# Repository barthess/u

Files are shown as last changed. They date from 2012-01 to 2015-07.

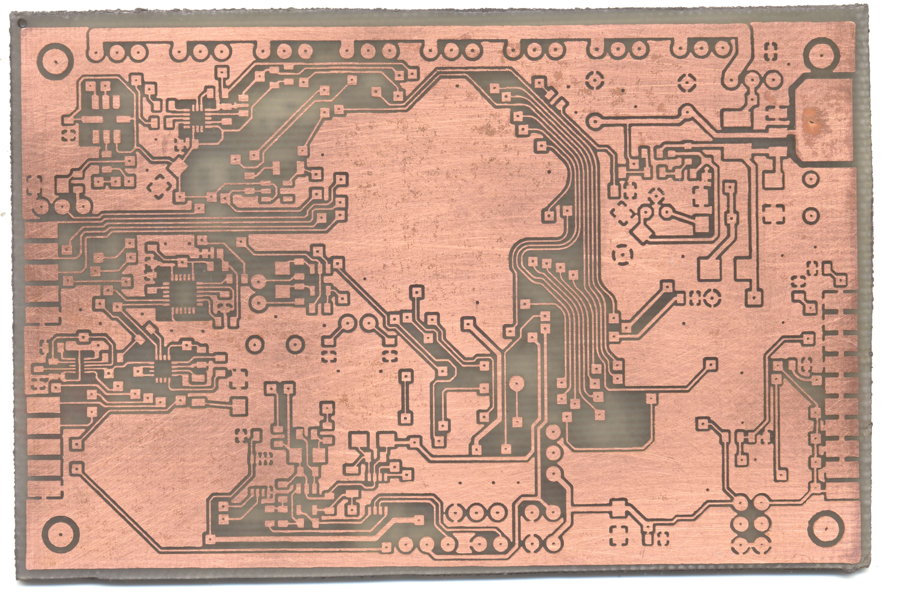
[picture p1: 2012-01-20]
hard/pcb/autopilot/pcb2.jpg

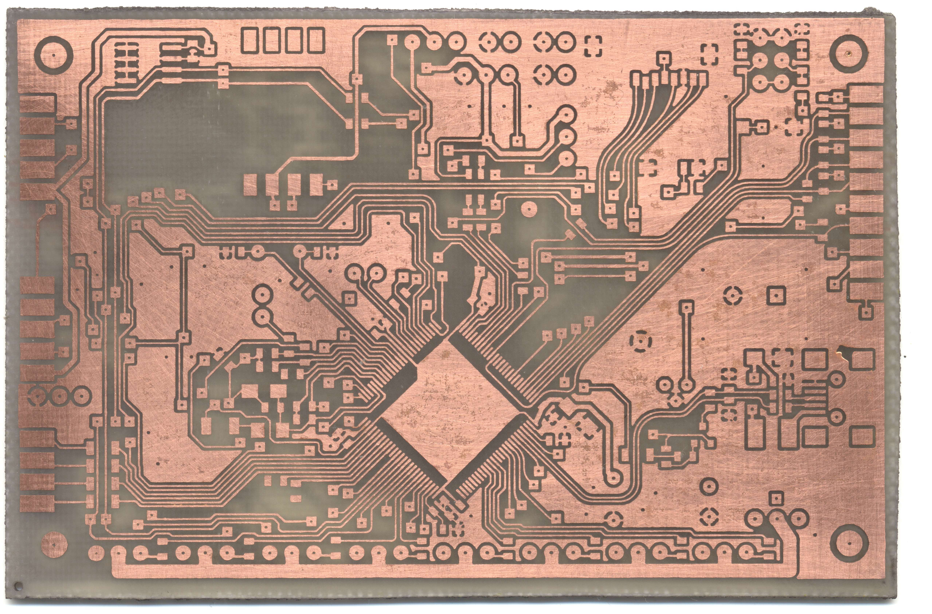
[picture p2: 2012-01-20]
hard/pcb/autopilot/pcb1.jpg

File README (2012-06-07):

A ChibiOS based autopilot. 

Goals of project:

0. Fun.
1. Education.

Copyright (C) 2012 Uladzimir Pylinski aka barthess (barthess@yandex.ru)

This program is free software: you can redistribute it and/or modify
it under the terms of the GNU General Public License as published by
the Free Software Foundation, either version 3 of the License, or
(at your option) any later version.

This program is distributed in the hope that it will be useful,
but WITHOUT ANY WARRANTY; without even the implied warranty of
MERCHANTABILITY or FITNESS FOR A PARTICULAR PURPOSE.  See the
GNU General Public License for more details.

You should have received a copy of the GNU General Public License
along with this program.  If not, see <http://www.gnu.org/licenses/>.

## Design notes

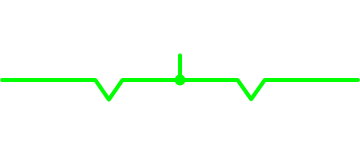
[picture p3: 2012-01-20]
soft/face/horizon_plane.png

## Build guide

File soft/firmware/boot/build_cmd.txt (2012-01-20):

 arm-none-eabi-gcc -mcpu=cortex-m3 -DTHUMB_PRESENT -mno-thumb-interwork -DTHUMB_NO_INTERWORKING -mthumb -DTHUMB -x assembler-with-cpp -c -g -O -Wa,-alh,-L boot.s -o ch.o

arm-none-eabi-ld -Tboot.ld -o ch.elf ch.o

arm-none-eabi-objcopy.exe -O binary ch.elf  ch.bin

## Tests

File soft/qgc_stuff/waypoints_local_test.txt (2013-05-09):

QGC WPL 120
0	1	1	22	0	1	0	0	14	0	520	1
1	0	1	21	0	1	0	0	4	2	520	1

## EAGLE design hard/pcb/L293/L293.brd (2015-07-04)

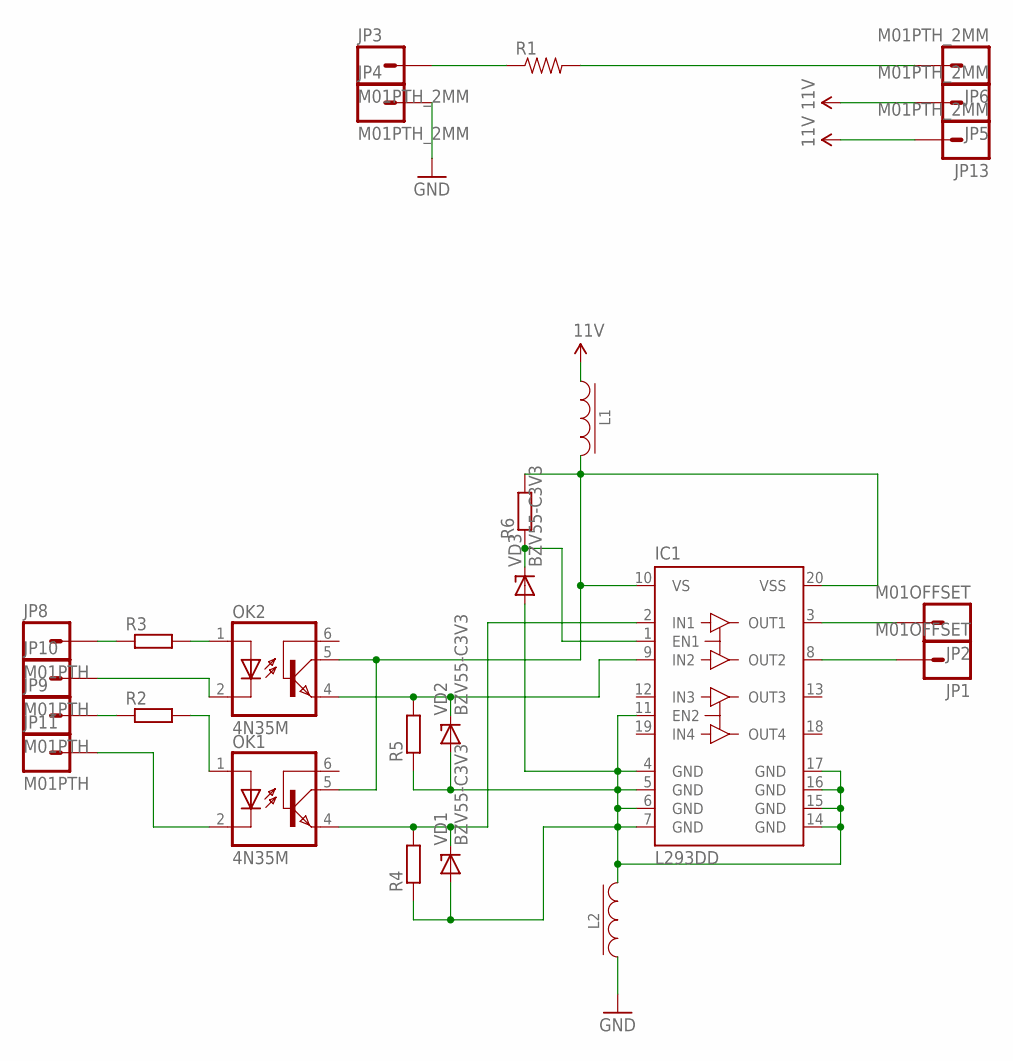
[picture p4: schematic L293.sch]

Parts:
IC1: L293DD; SO20
JP1, JP2: M01OFFSET; 1X01_OFFSET
JP3, JP4, JP5, JP6, JP13: M01PTH_2MM; 1X01_2MM
JP8, JP9, JP10, JP11: M01PTH; 1X01
L1, L2: DRA127
OK1, OK2: 4N35M; DIL06
R1: RESISTOR2512; R2512
R2, R3, R4, R5, R6: RESISTOR0805; 0805
VD1, VD2, VD3: BZV55-C3V3; SOD80C

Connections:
1.0V: JP5.1, JP13.1, L1.1
GND: JP4.1, L2.1
GND_DIRT: IC1.4 (GND), IC1.5 (GND), IC1.6 (GND), IC1.7 (GND), IC1.11 (EN2), IC1.14 (GND), IC1.15 (GND), IC1.16 (GND), IC1.17 (GND), L2.2, R4.1, R5.1, VD1.A, VD2.A, VD3.A
unnamed: IC1.8 (OUT2), JP1.1
unnamed: IC1.3 (OUT1), JP2.1
unnamed: JP3.1, R1.1
unnamed: JP6.1, R1.2
unnamed: JP9.1, R2.1
unnamed: JP8.1, R3.1
unnamed: IC1.10 (VS), IC1.20 (VSS), L1.2, OK1.5 (COL), OK2.5 (COL), R6.2
unnamed: OK1.1 (A), R2.2
unnamed: JP11.1, OK1.2 (C)
unnamed: JP10.1, OK2.2 (C)
unnamed: OK2.1 (A), R3.2
unnamed: IC1.1 (EN1), R6.1, VD3.C
unnamed: IC1.9 (IN2), OK2.4 (EMI), R5.2, VD2.C
unnamed: IC1.2 (IN1), OK1.4 (EMI), R4.2, VD1.C

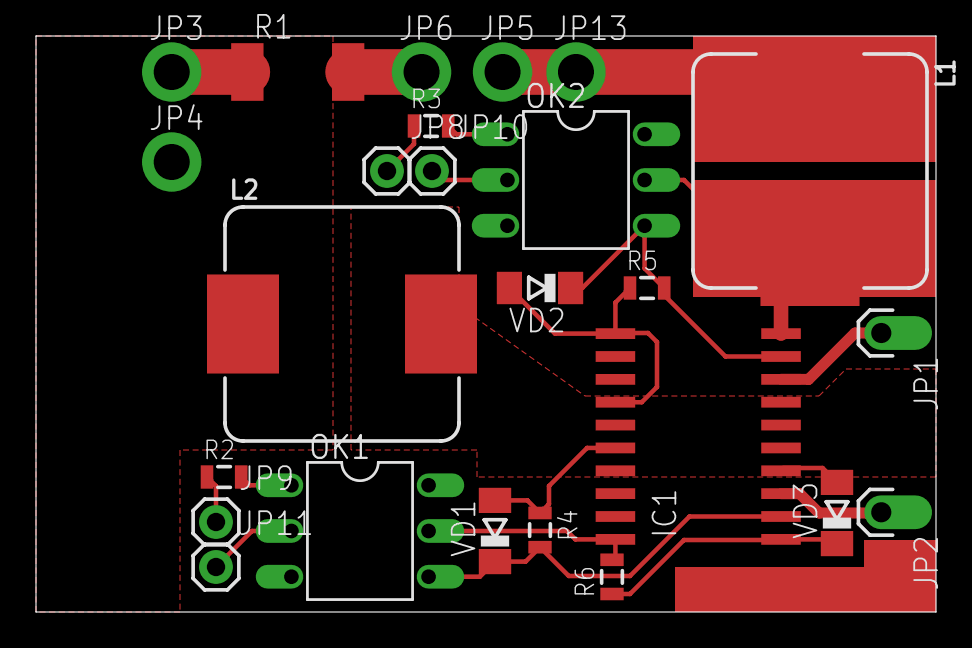
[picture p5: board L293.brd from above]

Board: 2 copper layers, 50.0 x 32.0 mm, 25 parts (0 on the bottom side), 17 nets.

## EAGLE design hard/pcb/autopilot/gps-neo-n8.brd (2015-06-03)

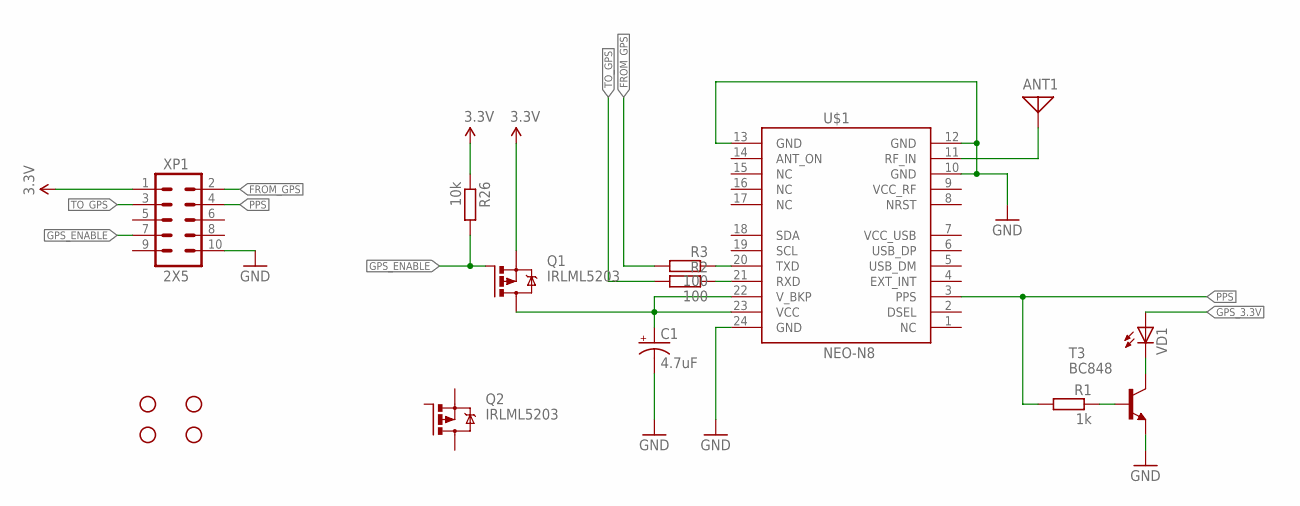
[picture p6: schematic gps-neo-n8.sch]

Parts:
ANT1: GPS_ANTENNA'35X35'; GPS_ANT_35X35MM
C1: 4.7uF; EIA3216-KIT
JP1, JP2, JP4, JP5: STAND-OFF
Q1, Q2: IRLML5203; MICRO3
R1: 1k; R0805
R2, R3: 100; R0805
R26: 10k; R0805
T3: BC848; SOT23
U$1: NEO-N8; NEO-M8
VD1: LED0805; LED-0805
XP1: 2X5; 2X5-PSEUDOSMD

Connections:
3.3V: Q1.2 (S), R26.1, XP1.1
FROM_GPS: R3.2, XP1.2
GND: C1.C (-), T3.2 (E), U$1.10 (GND), U$1.12 (GND), U$1.13 (GND), U$1.24 (GND), XP1.10
GPS_3.3V: C1.A (+), Q1.3 (D), U$1.22 (V_BKP), U$1.23 (VCC), VD1.A
GPS_ENABLE: Q1.1 (G), R26.2, XP1.7
unnamed: T3.3 (C), VD1.C
unnamed: ANT1.1, U$1.11 (RF_IN)
unnamed: R1.1, T3.1 (B)
unnamed: R2.1, U$1.21 (RXD)
unnamed: R3.1, U$1.20 (TXD)
PPS: R1.2, U$1.3 (PPS), XP1.4
TO_GPS: R2.2, XP1.3
VCC_RF: U$1.9 (VCC_RF)

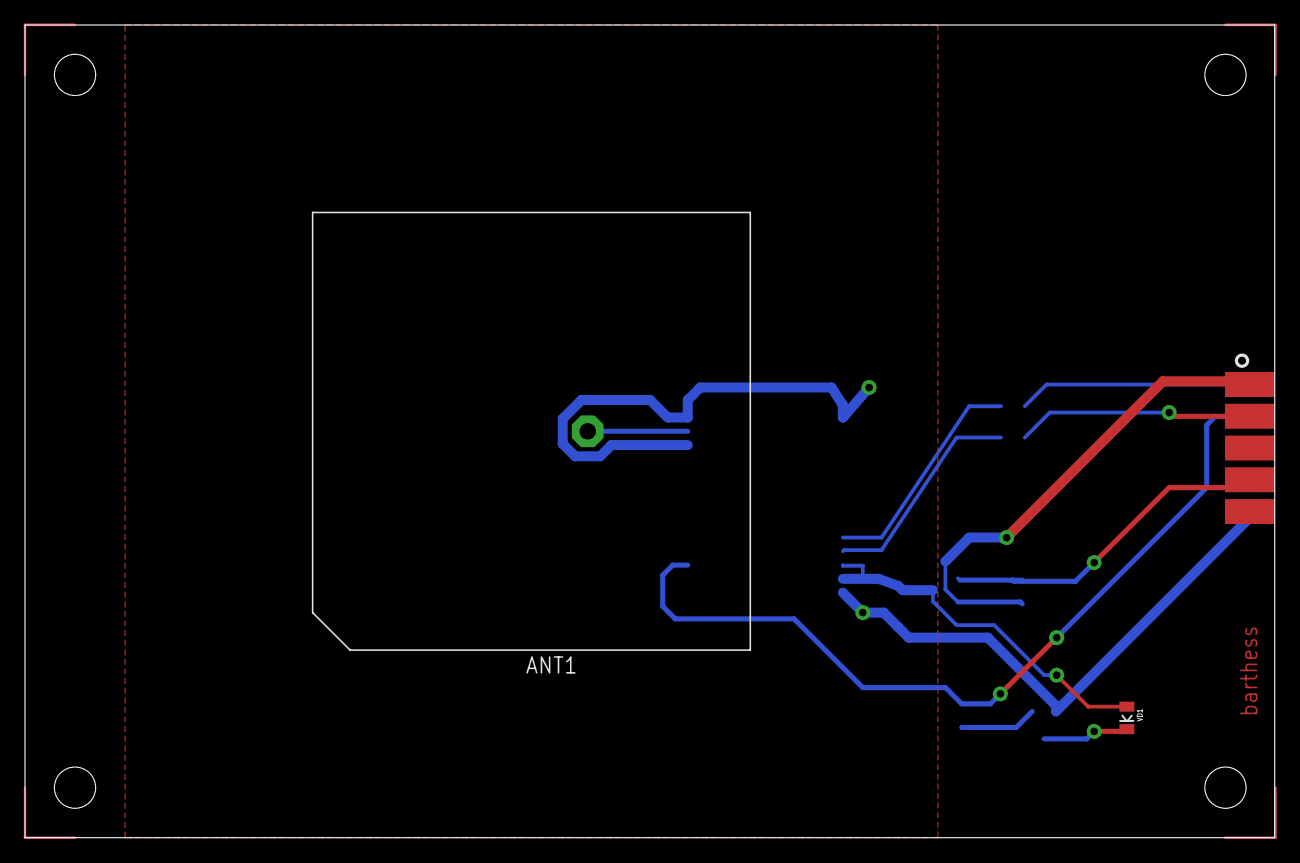
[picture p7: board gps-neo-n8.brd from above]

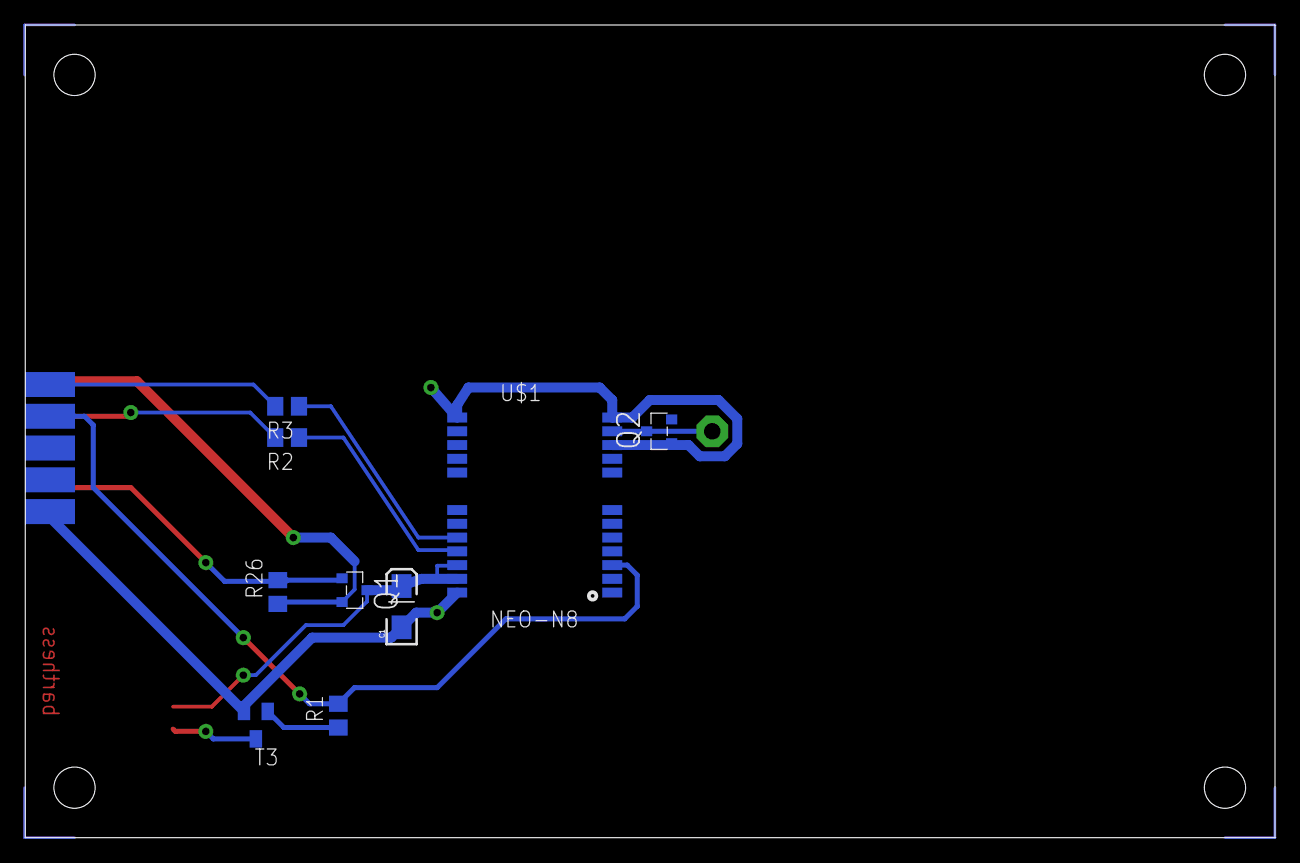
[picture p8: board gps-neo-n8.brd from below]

Board: 2 copper layers, 99.9 x 65.0 mm, 17 parts (9 on the bottom side), 12 nets.

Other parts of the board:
U$2: LOGO_CHIBIOS_SIGNAL

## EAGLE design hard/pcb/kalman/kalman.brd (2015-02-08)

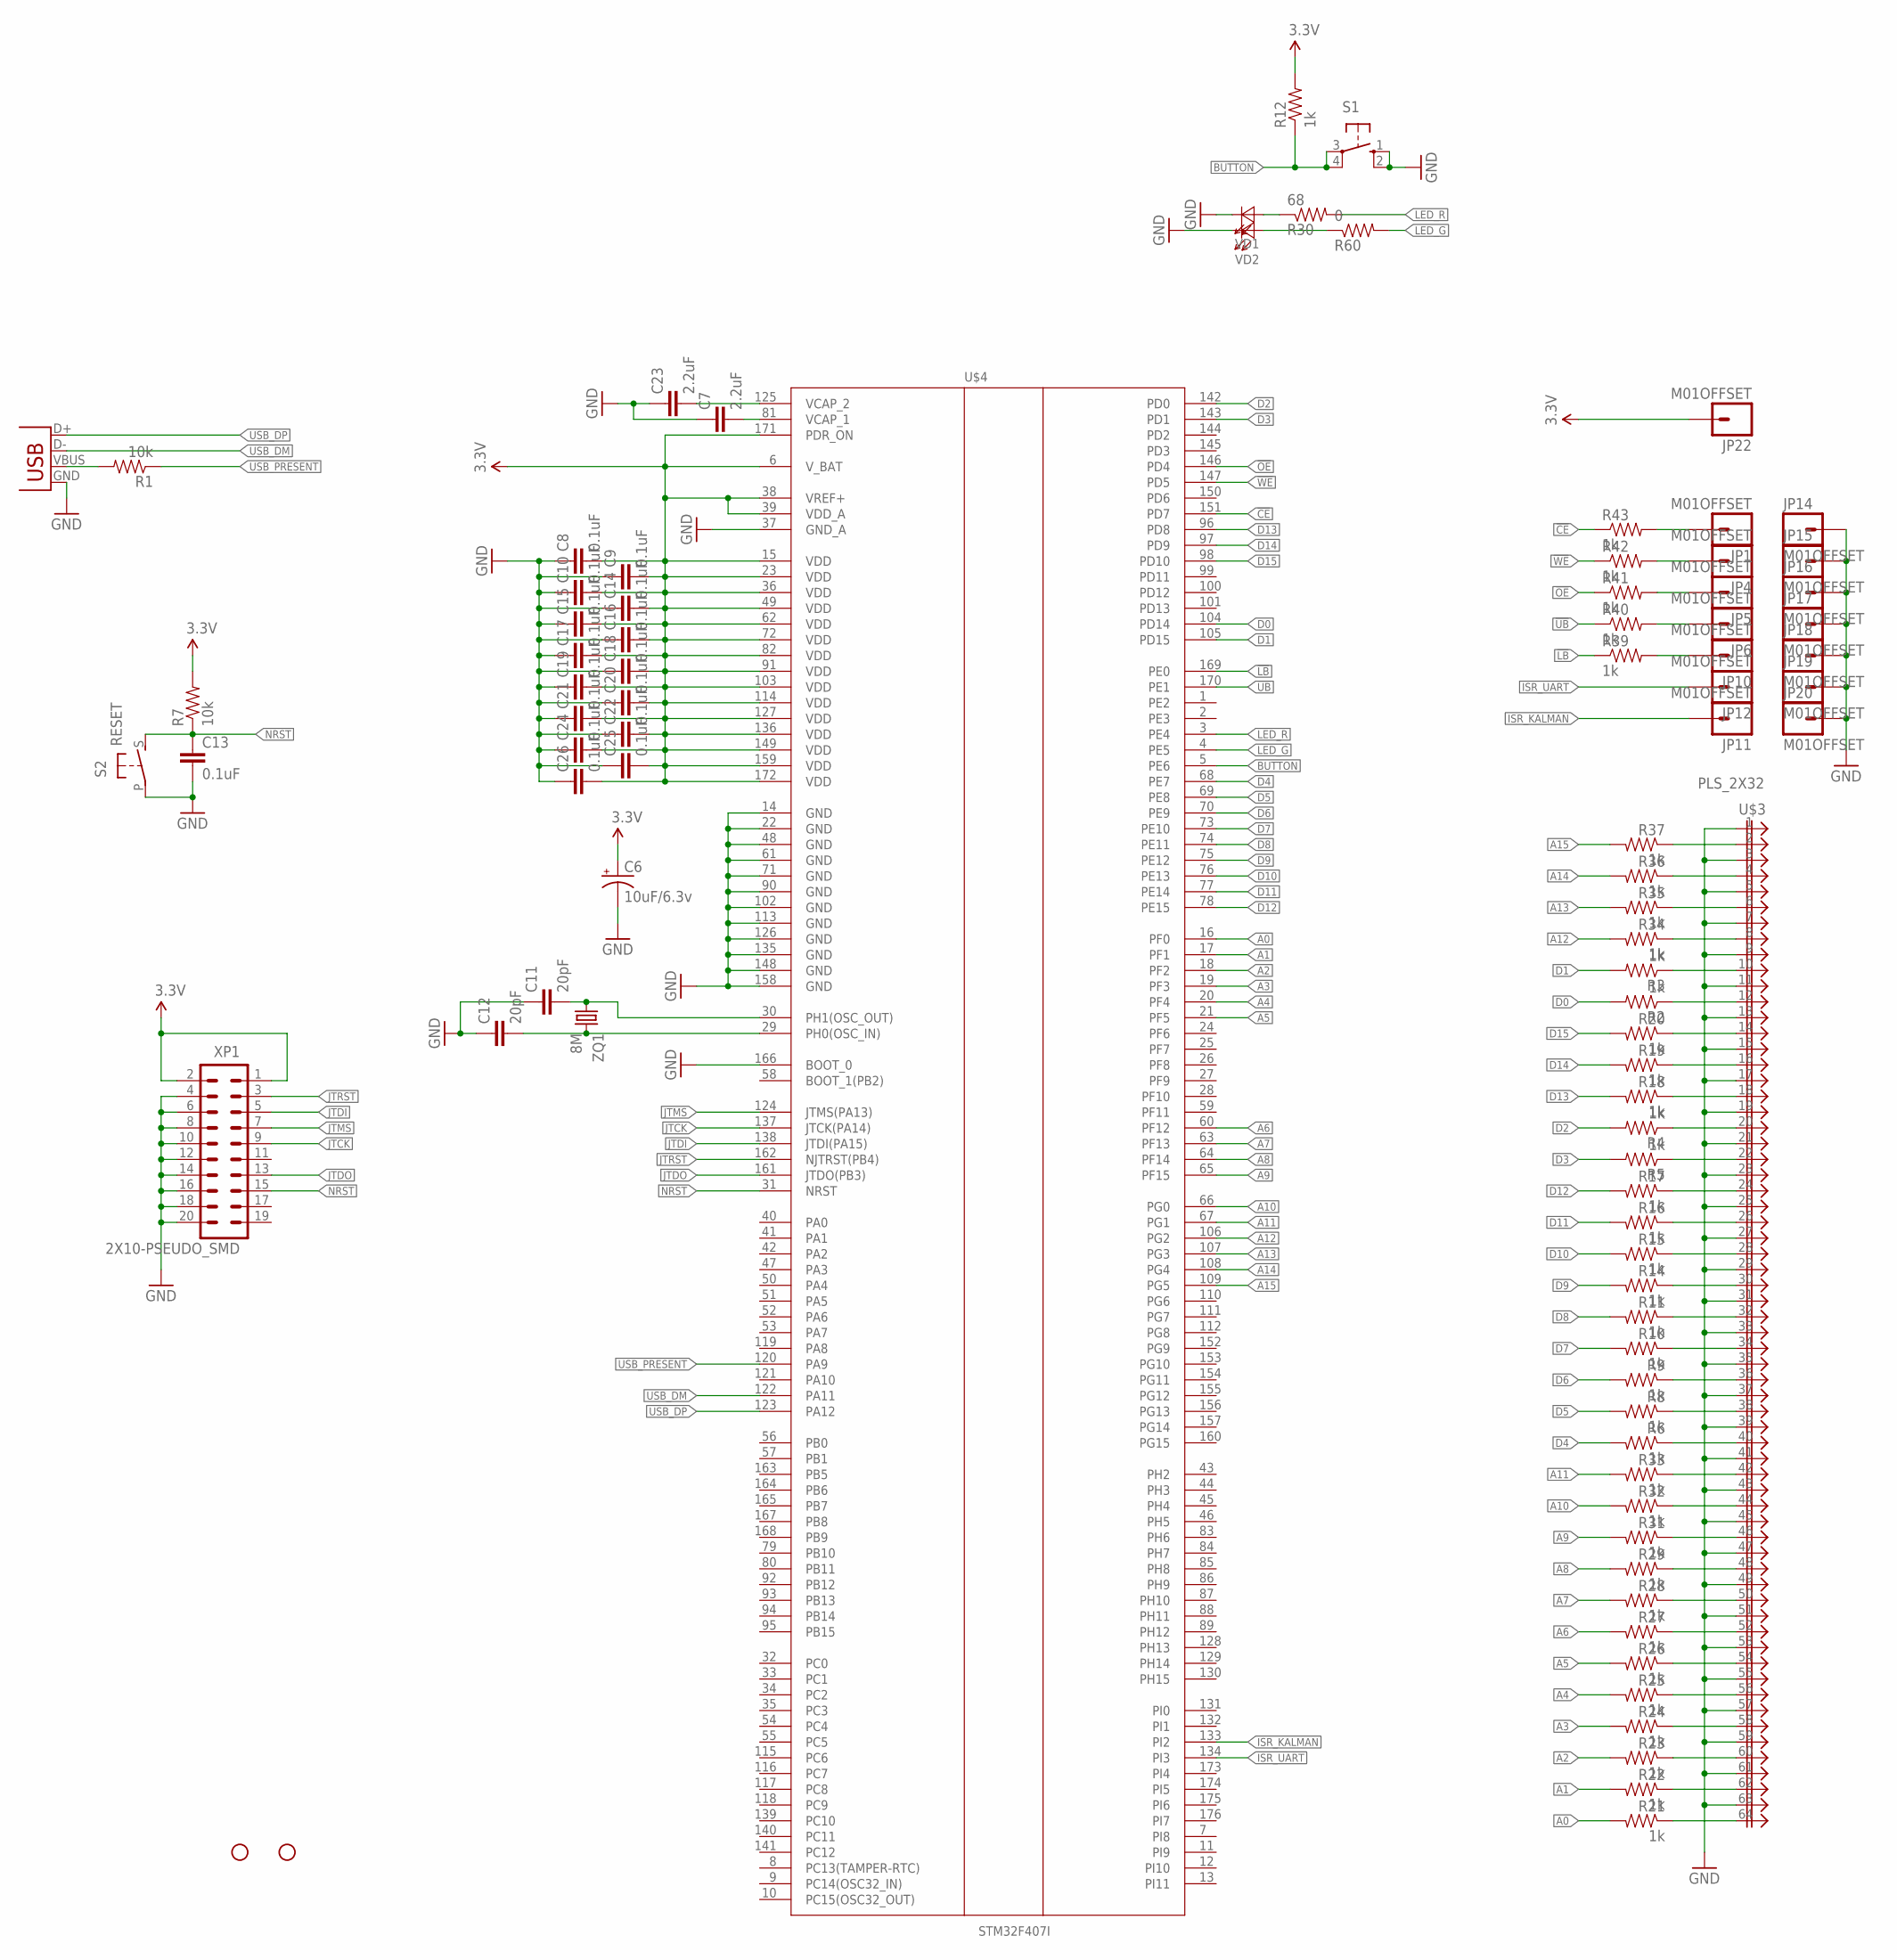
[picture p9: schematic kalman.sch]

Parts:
C6: 10uF/6.3v; EIA3216-KIT
C7, C23: 2.2uF; 0805
C8, C9, C10, C13, C14, C15, C16, C17, C18, C19, C20, C21, C22, C24, C25, C26: 0.1uF; 0805
C11, C12: 20pF; 0805
JP1, JP4, JP5, JP6, JP10, JP11, JP12, JP14, JP15, JP16, JP17, JP18, JP19, JP20, JP22: M01OFFSET; 1X01_OFFSET
JP7, JP8: STAND-OFF
R1, R7: 10k; 0805
R2, R3, R4, R5, R6, R8, R9, R10, R11, R12, R14, R15, R16, R17, R18, R19, R20, R21, R22, R23, R24, R25, R26, R27, R28, R29, R31, R32, R33, R34, R35, R36, R37, R39, R40, R41, R42, R43: 1k; 0805
R30: 68; 0805
R60: 0; 0805
S1: 10-XX; B3F-10XX
S2: RESET; BUTTON_6X3.5
U$3: PLS_2X32; PLS_2X32_PSEUDOSMD
U$4: STM32F407I; TQFP176(1.5X0.25)
VD1, VD2: LED1206; LED-1206
X1: USB-SMD-NS; USB-MINIB-NOSTOP
XP1: 2X10-PSEUDO_SMD; PLD_2X10_PSEUDOSMD
ZQ1: 8M; CTS406

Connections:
3.3V: C6.A (+), C8.2, C9.2, C10.2, C14.2, C15.2, C16.2, C17.2, C18.2, C19.2, C20.2, C21.2, C22.2, C24.2, C25.2, C26.2, JP22.1, R7.2, R12.2, U$4.6 (V_BAT), U$4.15 (VDD), U$4.23 (VDD), U$4.36 (VDD), U$4.38 (VREF+), U$4.39 (VDD_A), U$4.49 (VDD), U$4.62 (VDD), U$4.72 (VDD), U$4.82 (VDD), U$4.91 (VDD), U$4.103 (VDD), U$4.114 (VDD), U$4.127 (VDD), U$4.136 (VDD), U$4.149 (VDD), U$4.159 (VDD), U$4.171 (PDR_ON), U$4.172 (VDD), XP1.1, XP1.2
5V_USB: R1.2, X1.VBUS
!CE: R43.1, U$4.151 (PD7)
!LB: R39.1, U$4.169 (PE0)
!OE: R41.1, U$4.146 (PD4)
!UB: R40.1, U$4.170 (PE1)
!WE: R42.1, U$4.147 (PD5)
A0: R21.2, U$4.16 (PF0)
A1: R22.2, U$4.17 (PF1)
A2: R23.2, U$4.18 (PF2)
A3: R24.2, U$4.19 (PF3)
A4: R25.2, U$4.20 (PF4)
A5: R26.2, U$4.21 (PF5)
A6: R27.2, U$4.60 (PF12)
A7: R28.2, U$4.63 (PF13)
A8: R29.2, U$4.64 (PF14)
A9: R31.2, U$4.65 (PF15)
A10: R32.2, U$4.66 (PG0)
A11: R33.2, U$4.67 (PG1)
A12: R34.2, U$4.106 (PG2)
A13: R35.2, U$4.107 (PG3)
A14: R36.2, U$4.108 (PG4)
A15: R37.2, U$4.109 (PG5)
BUTTON: R12.1, S1.3, S1.4 (P1), U$4.5 (PE6)
D0: R2.2, U$4.104 (PD14)
D1: R3.2, U$4.105 (PD15)
D2: R4.2, U$4.142 (PD0)
D3: R5.2, U$4.143 (PD1)
D4: R6.2, U$4.68 (PE7)
D5: R8.2, U$4.69 (PE8)
D6: R9.2, U$4.70 (PE9)
D7: R10.2, U$4.73 (PE10)
D8: R11.2, U$4.74 (PE11)
D9: R14.2, U$4.75 (PE12)
D10: R15.2, U$4.76 (PE13)
D11: R16.2, U$4.77 (PE14)
D12: R17.2, U$4.78 (PE15)
D13: R18.2, U$4.96 (PD8)
D14: R19.2, U$4.97 (PD9)
D15: R20.2, U$4.98 (PD10)
GND: C6.C (-), C7.1, C8.1, C9.1, C10.1, C11.1, C12.1, C13.2, C14.1, C15.1, C16.1, C17.1, C18.1, C19.1, C20.1, C21.1, C22.1, C23.1, C24.1, C25.1, C26.1, JP14.1, JP15.1, JP16.1, JP17.1, JP18.1, JP19.1, JP20.1, S1.1 (S), S1.2 (S1), S2.P, U$3.1, U$3.3, U$3.5, U$3.7, U$3.9, U$3.11, U$3.13, U$3.15, U$3.17, U$3.19, U$3.21, U$3.23, U$3.25, U$3.27, U$3.29, U$3.31, U$3.33, U$3.35, U$3.37, U$3.39, U$3.41, U$3.43, U$3.45, U$3.47, U$3.49, U$3.51, U$3.53, U$3.55, U$3.57, U$3.59, U$3.61, U$3.63, U$4.14 (GND), U$4.22 (GND), U$4.37 (GND_A), U$4.48 (GND), U$4.61 (GND), U$4.71 (GND), U$4.90 (GND), U$4.102 (GND), U$4.113 (GND), U$4.126 (GND), U$4.135 (GND), U$4.148 (GND), U$4.158 (GND), U$4.166 (BOOT_0), VD1.C, VD2.C, X1.GND, XP1.4, XP1.6, XP1.8, XP1.10, XP1.12, XP1.14, XP1.16, XP1.18, XP1.20
ISR_KALMAN: JP11.1, U$4.133 (PI2)
ISR_UART: JP12.1, U$4.134 (PI3)
JTCK: U$4.137 (JTCK(PA14)), XP1.9
JTDI: U$4.138 (JTDI(PA15)), XP1.5
JTDO: U$4.161 (JTDO(PB3)), XP1.13
JTMS: U$4.124 (JTMS(PA13)), XP1.7
JTRST: U$4.162 (NJTRST(PB4)), XP1.3
LED_G: R60.2, U$4.4 (PE5)
LED_R: R30.2, U$4.3 (PE4)
unnamed: C23.2, U$4.125 (VCAP_2)
unnamed: C7.2, U$4.81 (VCAP_1)
unnamed: JP1.1, R43.2
unnamed: R5.1, U$3.22
unnamed: R4.1, U$3.20
unnamed: R18.1, U$3.18
unnamed: R19.1, U$3.16
unnamed: R6.1, U$3.40
unnamed: R8.1, U$3.38
unnamed: R21.1, U$3.64
unnamed: R9.1, U$3.36
unnamed: R30.1, VD1.A
unnamed: R22.1, U$3.62
unnamed: R10.1, U$3.34
unnamed: R11.1, U$3.32
unnamed: R14.1, U$3.30
unnamed: R15.1, U$3.28
unnamed: R16.1, U$3.26
unnamed: R17.1, U$3.24
unnamed: R20.1, U$3.14
unnamed: C12.2, U$4.29 (PH0(OSC_IN)), ZQ1.3 (2)
unnamed: C11.2, U$4.30 (PH1(OSC_OUT)), ZQ1.1
unnamed: R2.1, U$3.12
unnamed: R3.1, U$3.10
unnamed: R23.1, U$3.60
unnamed: R24.1, U$3.58
unnamed: R25.1, U$3.56
unnamed: R26.1, U$3.54
unnamed: R27.1, U$3.52
unnamed: R28.1, U$3.50
unnamed: R60.1, VD2.A
unnamed: R29.1, U$3.48
unnamed: R31.1, U$3.46
unnamed: R32.1, U$3.44
unnamed: R33.1, U$3.42
unnamed: R34.1, U$3.8
unnamed: R35.1, U$3.6
unnamed: R36.1, U$3.4
unnamed: R37.1, U$3.2
unnamed: JP4.1, R42.2
unnamed: JP5.1, R41.2
unnamed: JP6.1, R40.2
unnamed: JP10.1, R39.2
NRST: C13.1, R7.1, S2.S, U$4.31 (NRST), XP1.15
USB_DM: U$4.122 (PA11), X1.D-
USB_DP: U$4.123 (PA12), X1.D+
USB_PRESENT: R1.1, U$4.120 (PA9)

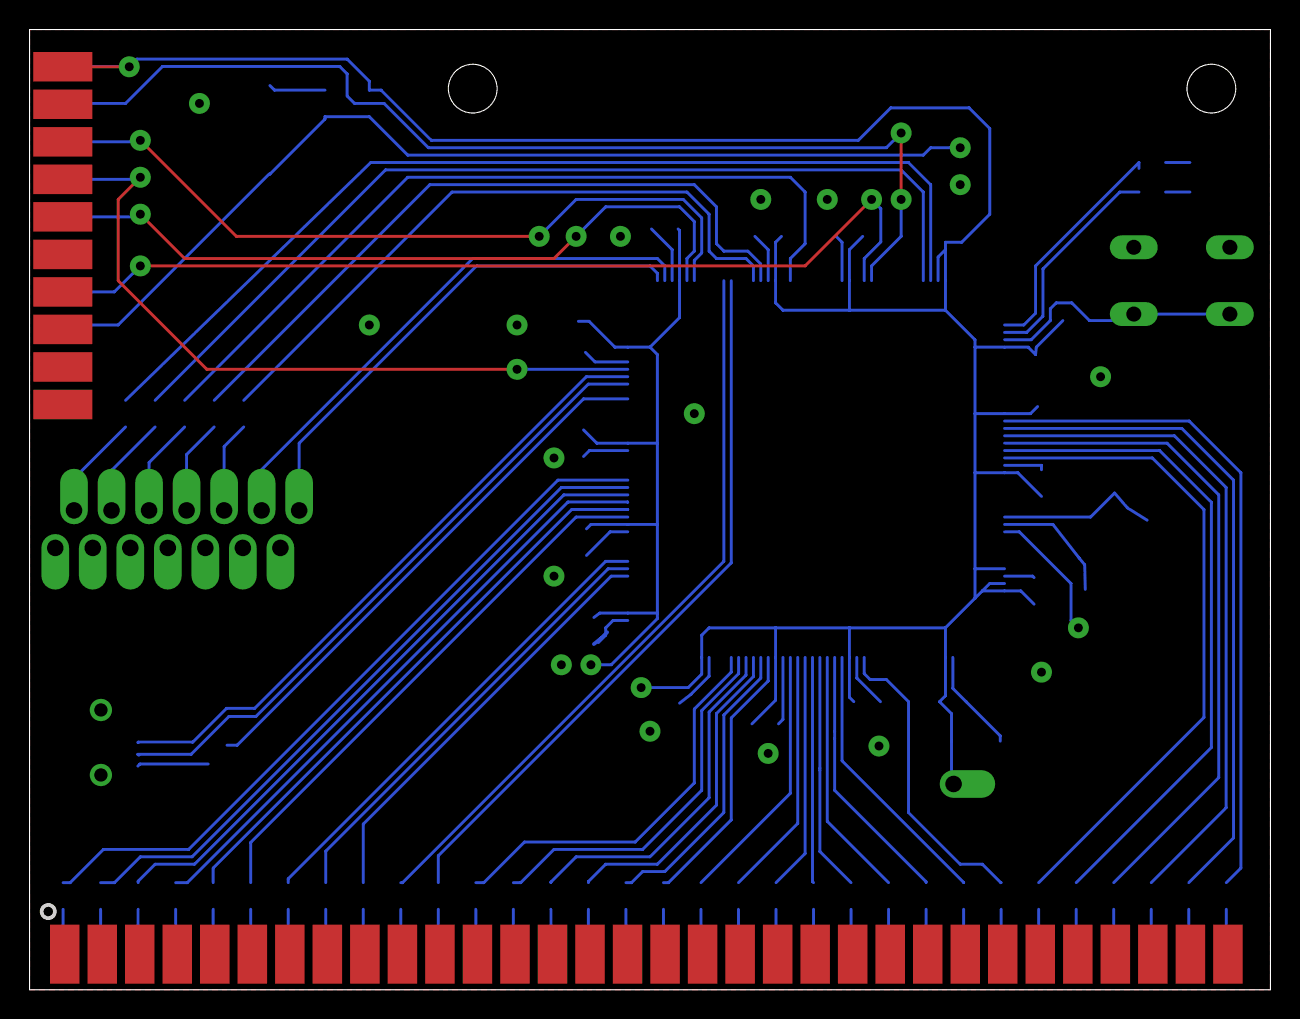
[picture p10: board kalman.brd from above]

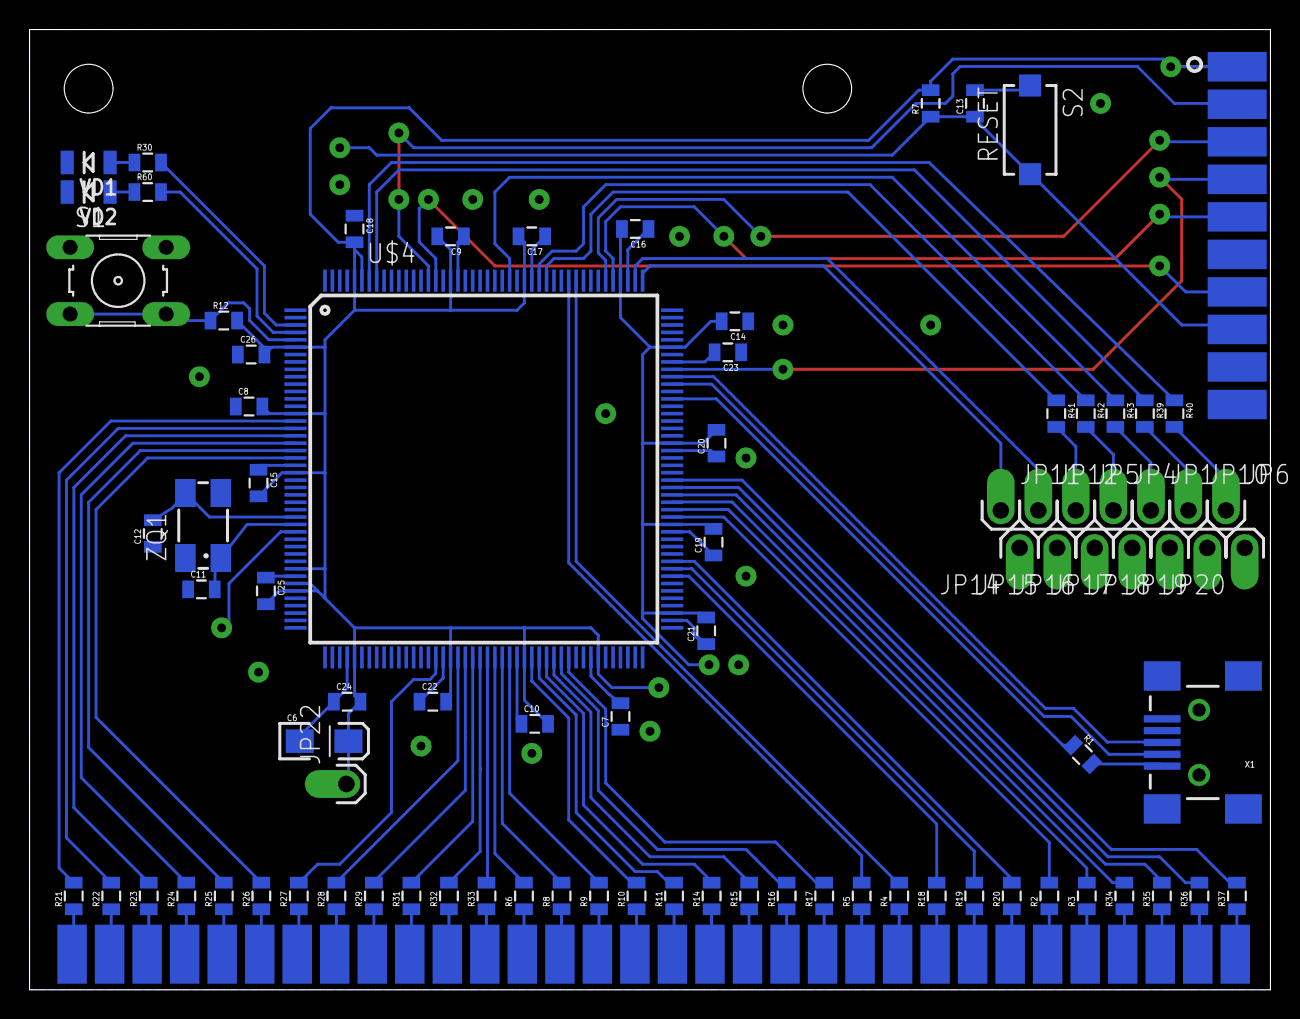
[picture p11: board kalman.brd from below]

Board: 2 copper layers, 84.0 x 65.0 mm, 89 parts (86 on the bottom side), 97 nets.

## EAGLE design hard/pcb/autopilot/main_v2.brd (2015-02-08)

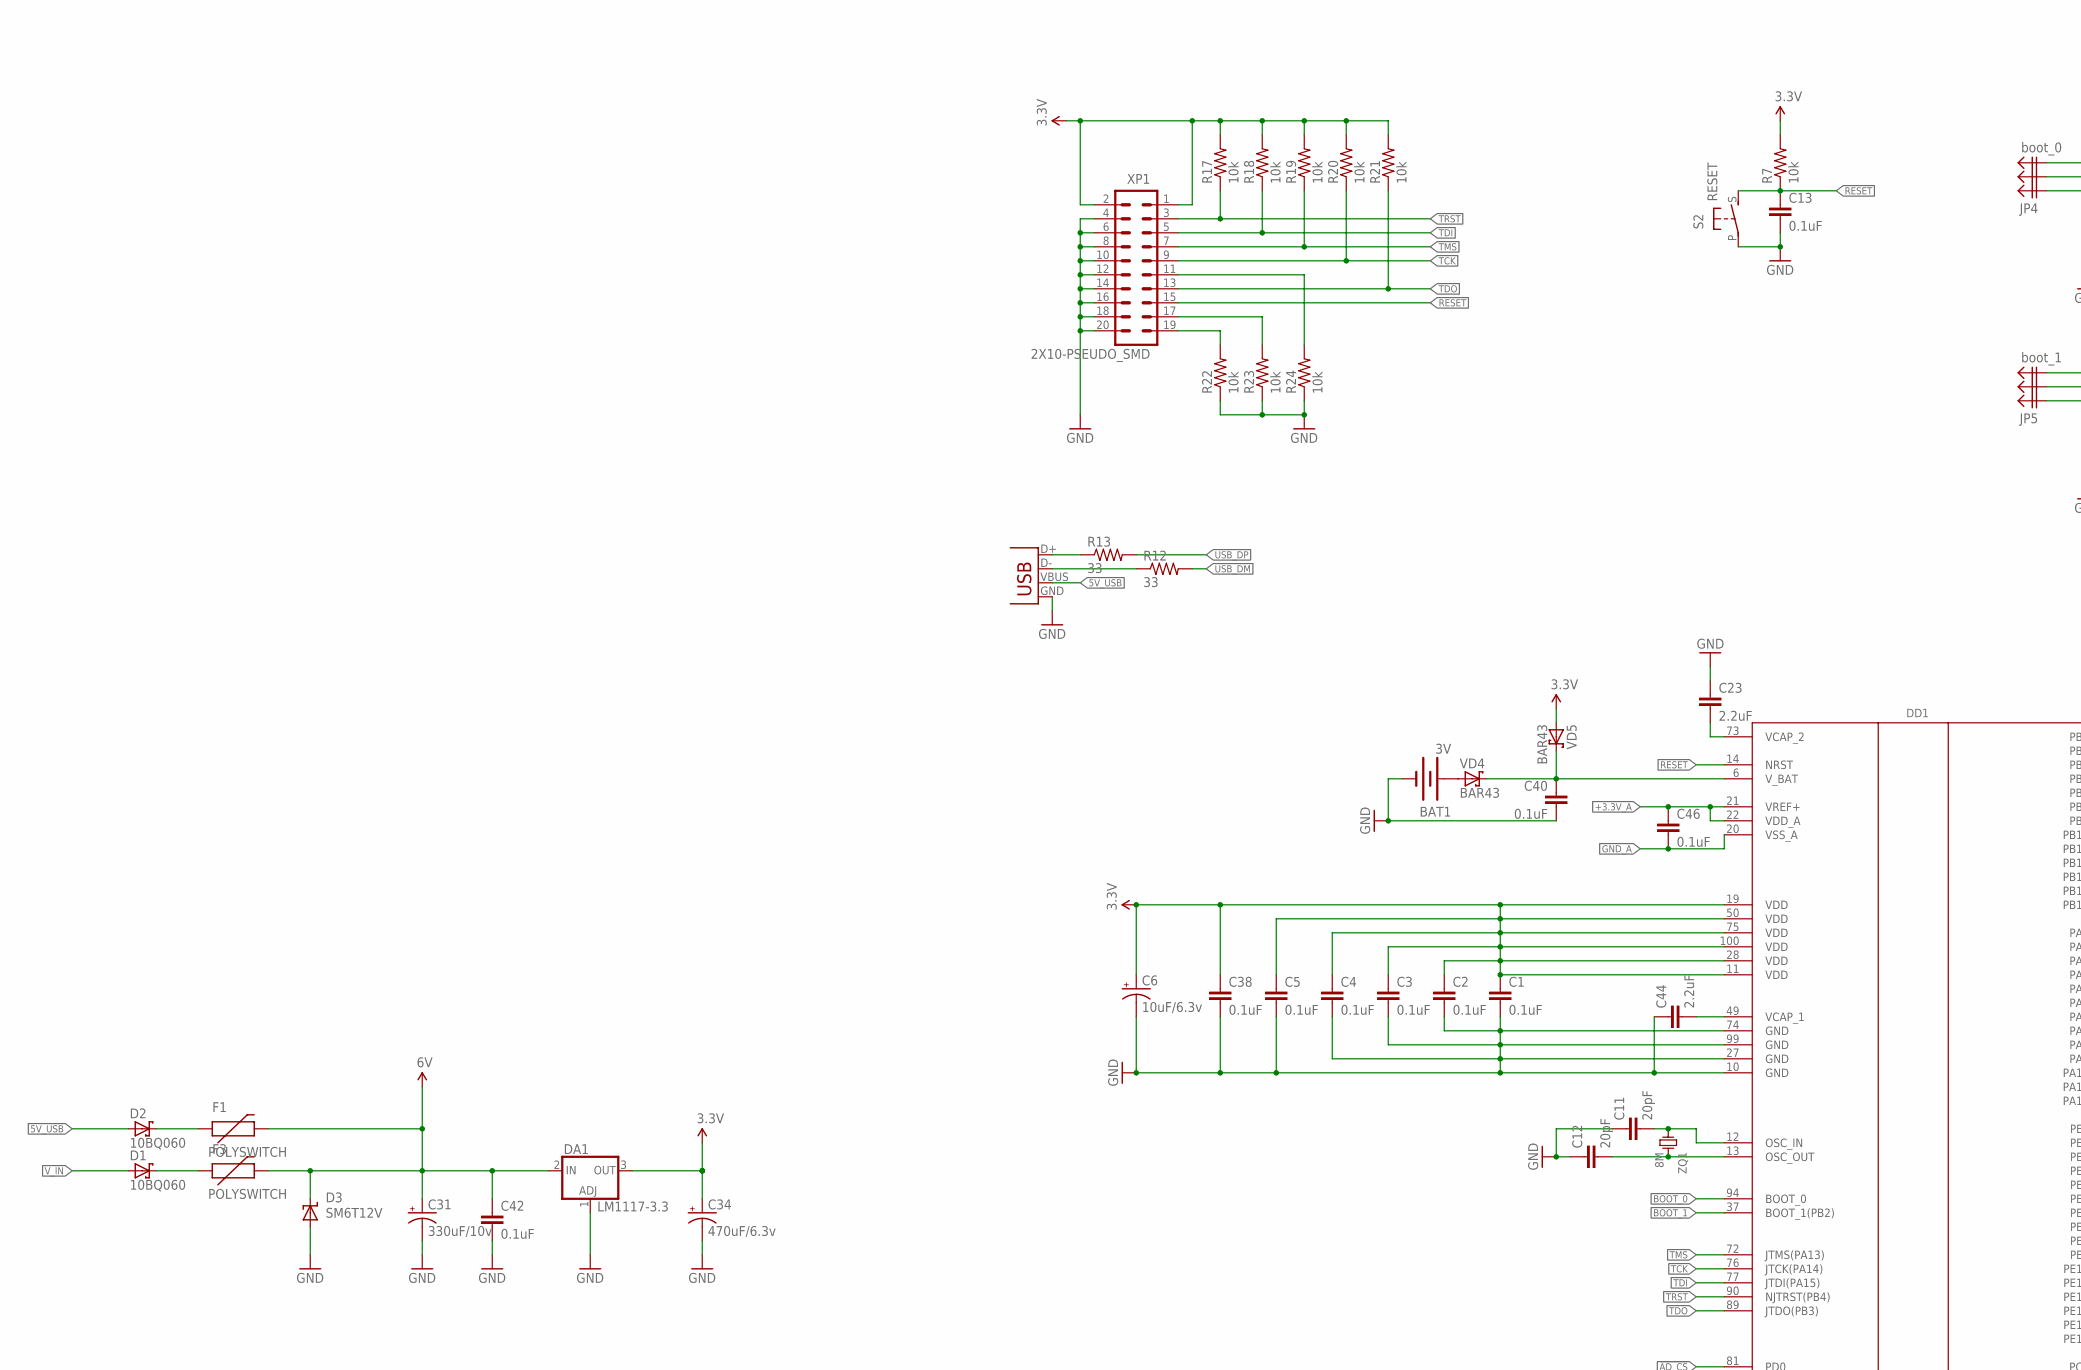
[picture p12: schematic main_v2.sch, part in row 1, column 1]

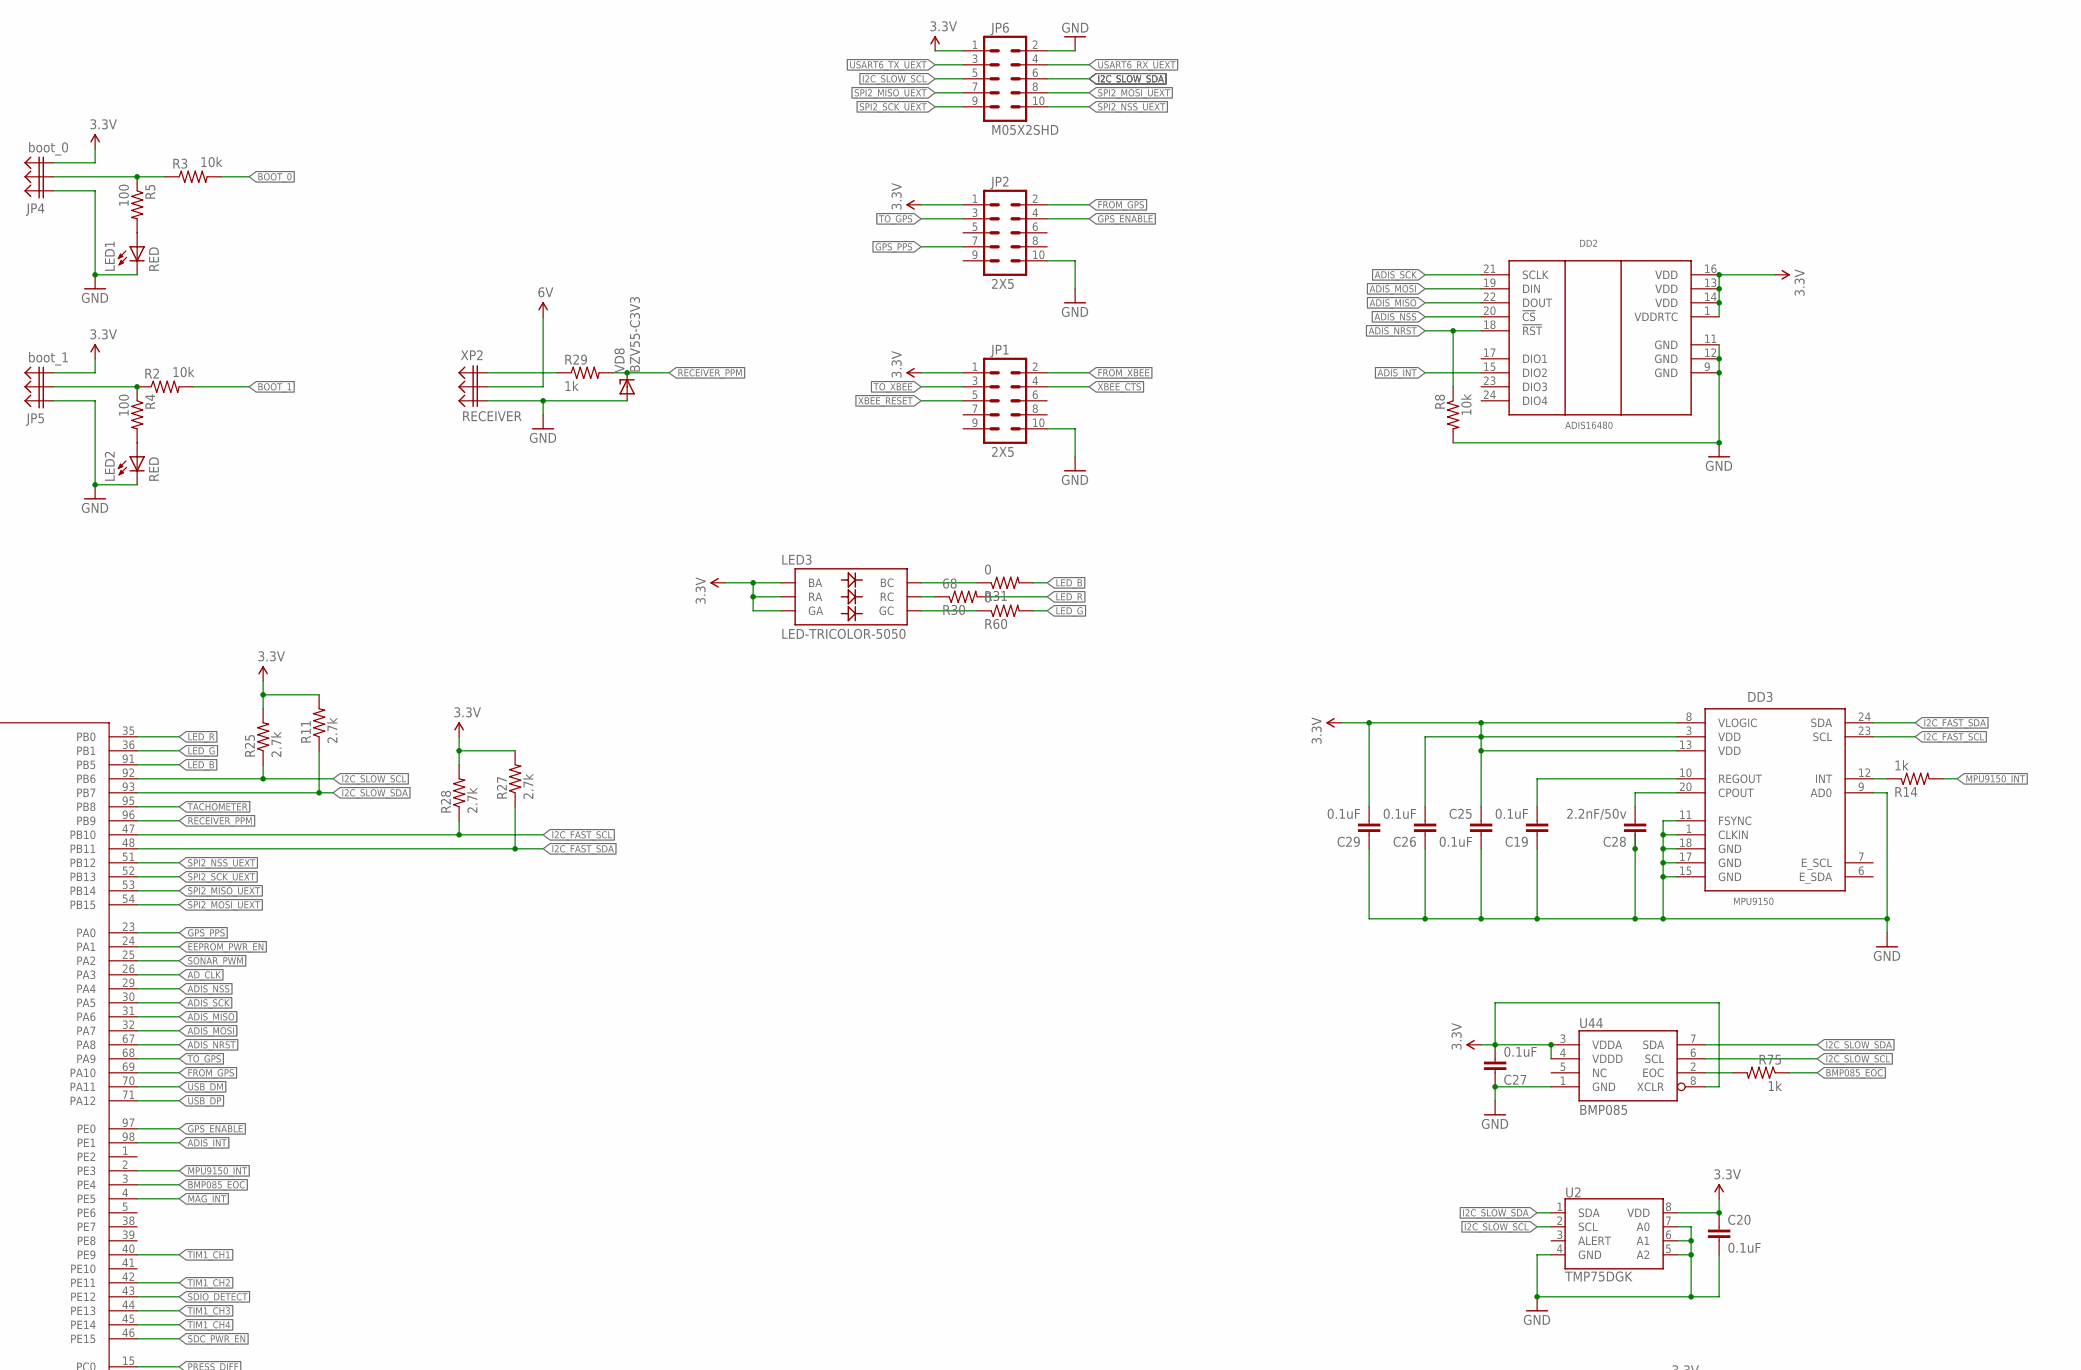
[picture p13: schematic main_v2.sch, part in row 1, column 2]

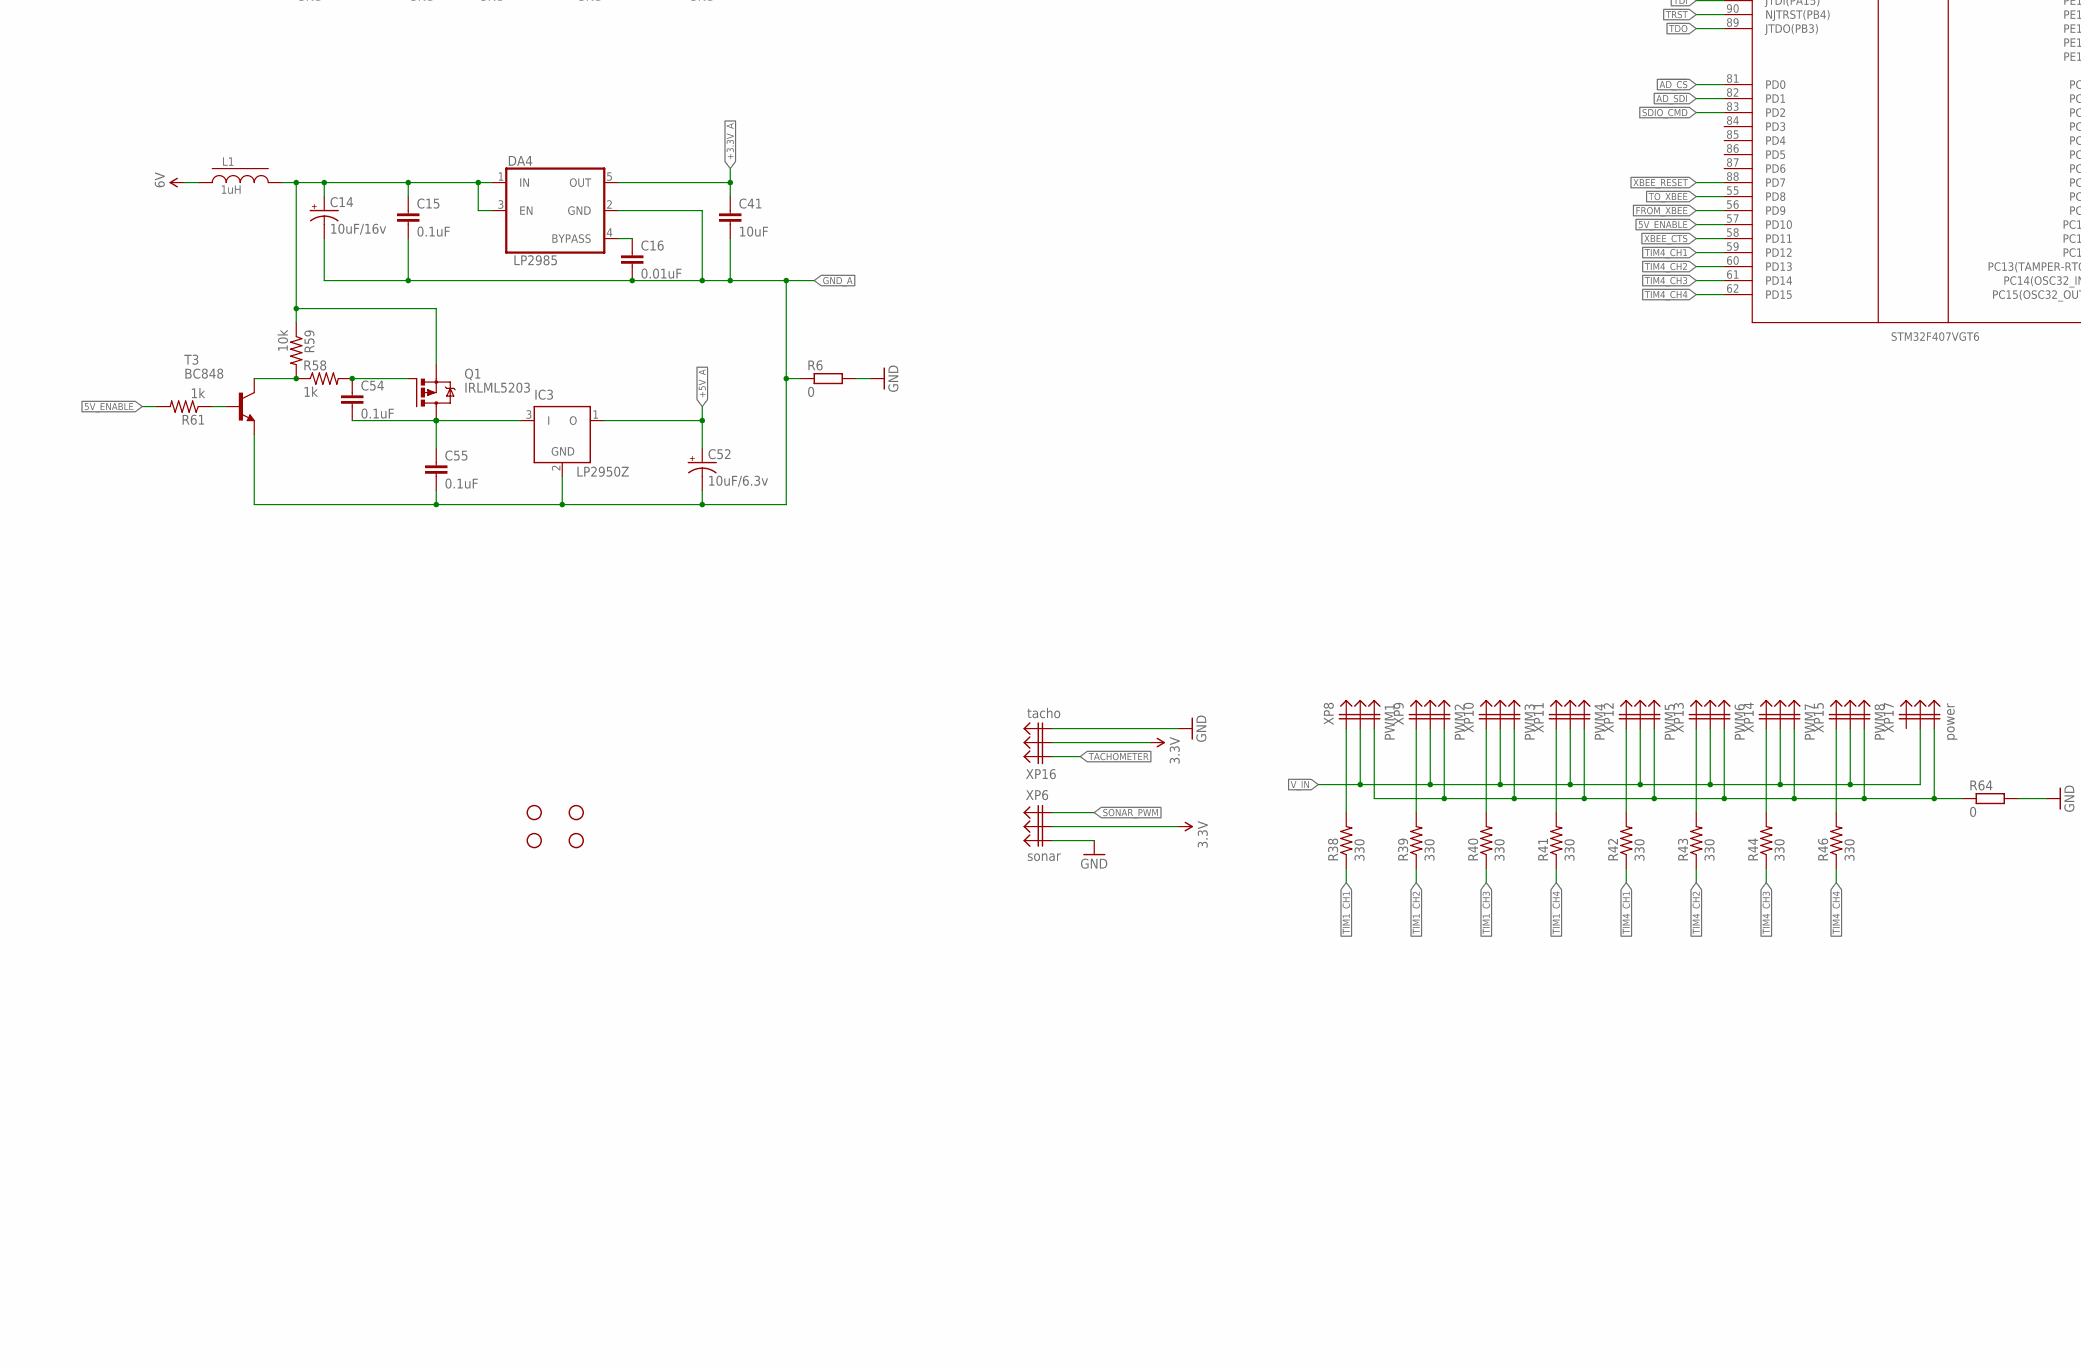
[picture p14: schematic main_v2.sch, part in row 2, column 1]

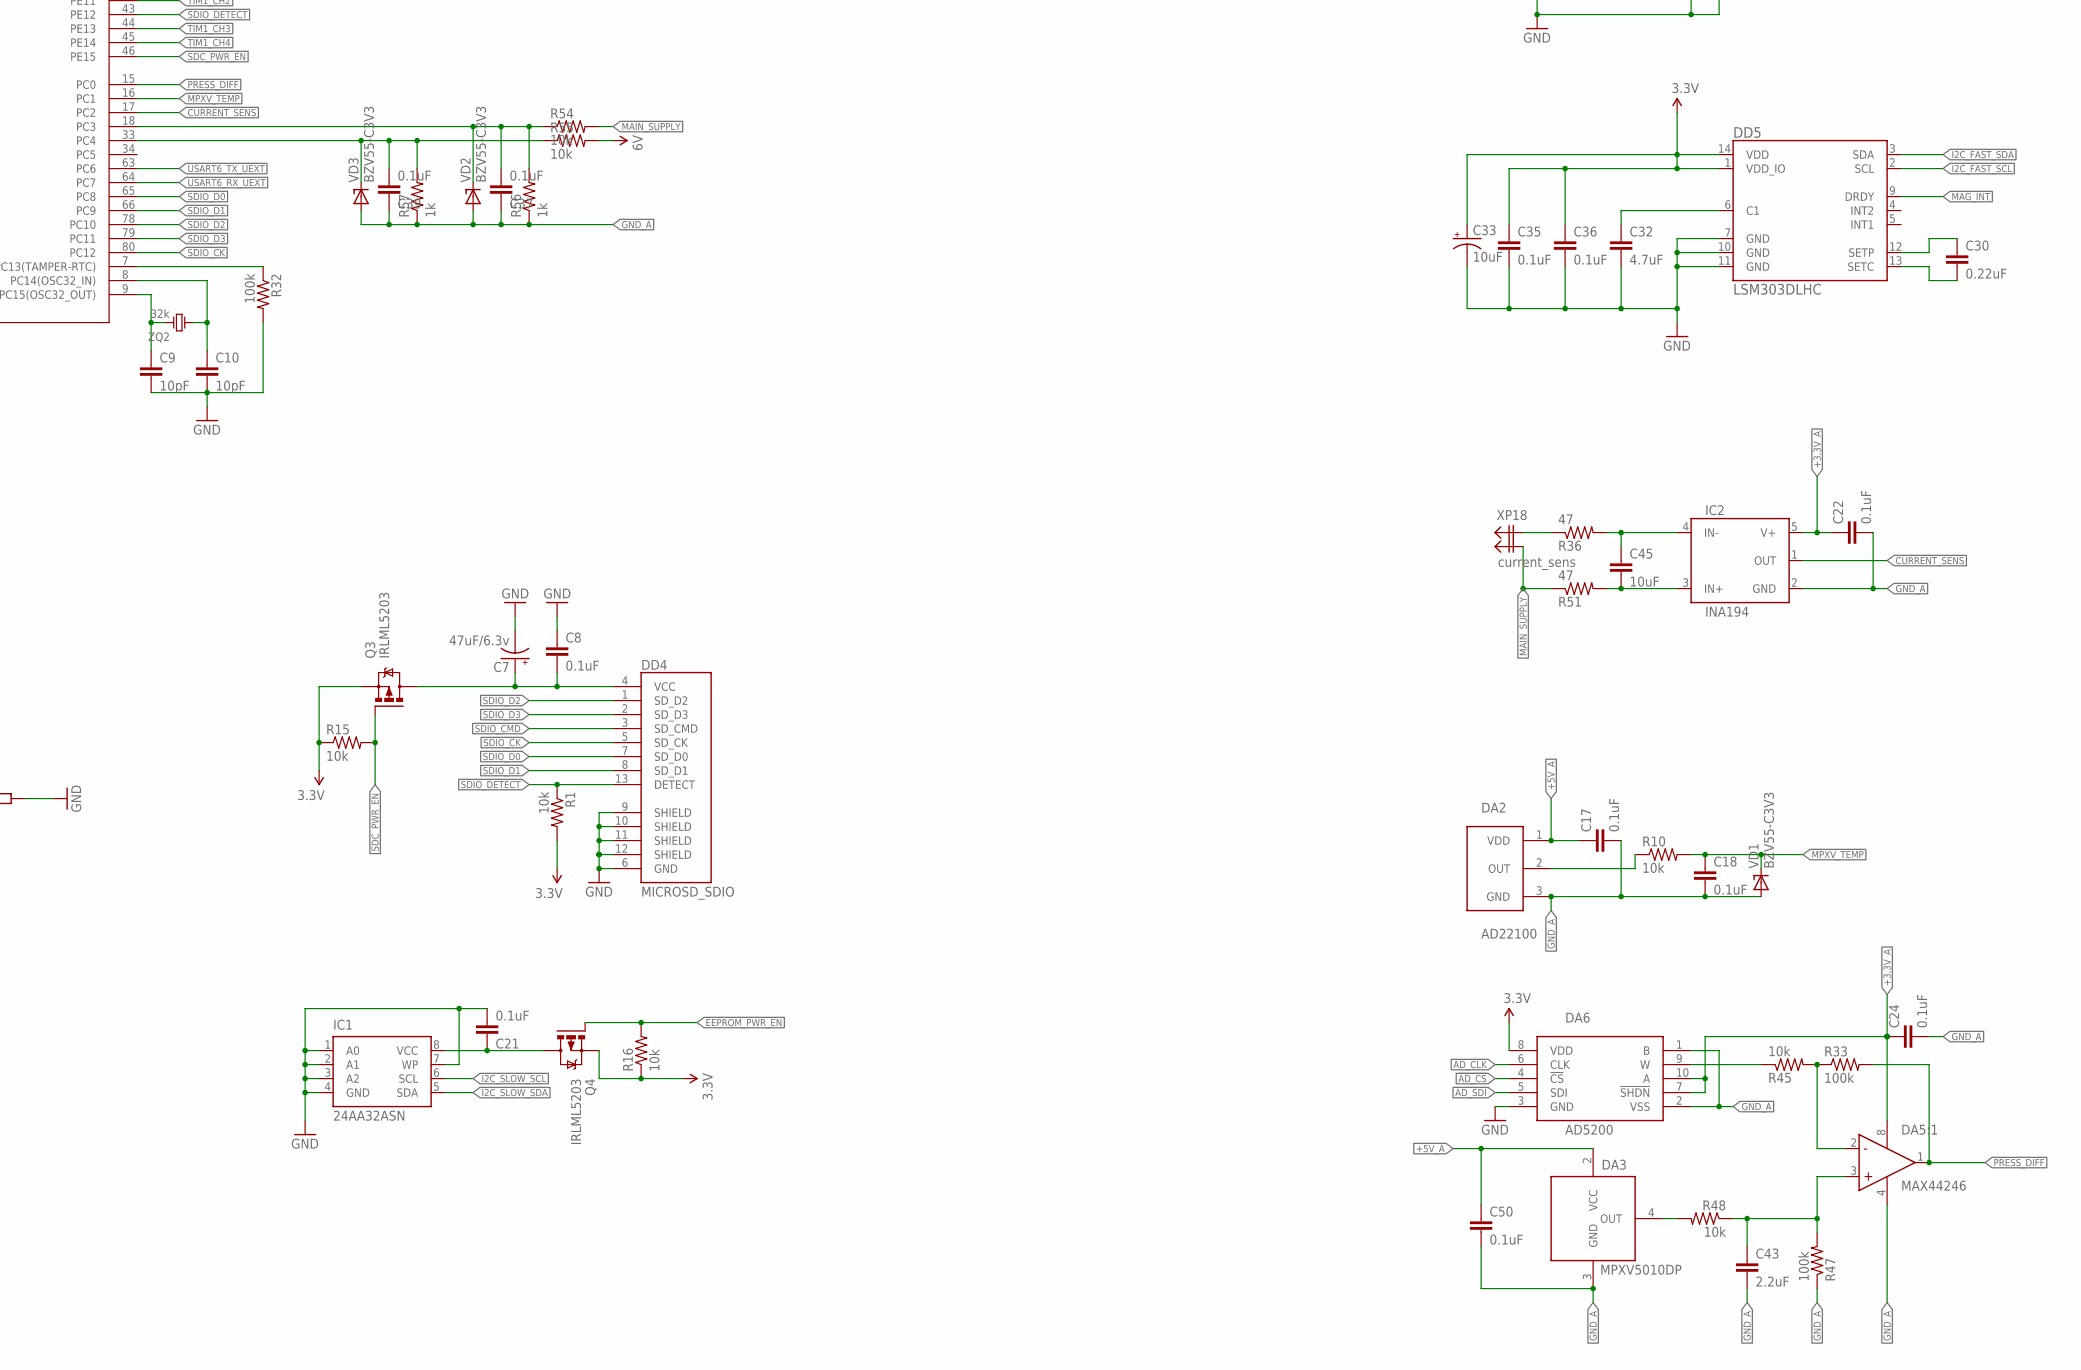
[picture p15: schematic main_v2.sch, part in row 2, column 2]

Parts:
BAT1: 3V; BATTCOM_20MM_PTH
C1, C2, C3, C4, C5, C8, C13, C15, C17, C18, C19, C20, C21, C22, C24, C25, C26, C27, C29, C35, C36, C37, C38, C39, C40, C42, C46, C50, C54, C55: 0.1uF; 0805
C6, C52: 10uF/6.3v; EIA3216-KIT
C7: 47uF/6.3v; EIA3216-KIT
C9, C10: 10pF; 0805
C11, C12: 20pF; 0805
C14: 10uF/16v; EIA3216-KIT
C16: 0.01uF; 0805
C23, C43, C44: 2.2uF; 0805
C28: 2.2nF/50v; 0805
C30: 0.22uF; 0805
C31: 330uF/10v; EIA7343
C32: 4.7uF; 0805
C33: 10uF; EIA3216-KIT
C34: 470uF/6.3v; EIA7343
C41, C45: 10uF; 1206
D1, D2: 10BQ060; SMB
D3: SM6T12V; SMBJ
DA1: LM1117-3.3; TO252
DA2: AD22100; TO92
DA3: MPXV5010DP; 482
DA4: LP2985; SOT23-5
DA5: MAX44246; MSOP8
DA6: AD5200; MSOP10
DD1: STM32F407VGT6; TQFP100
DD2: ADIS16480
DD3: MPU9150; QFN-24-NP
DD4: MICROSD_SDIO; MICROSD
DD5: LSM303DLHC; LGA14
F1, F3: POLYSWITCH; 1812
IC1: 24AA32ASN; SO-08
IC2: INA194; SOT23-5
IC3: LP2950Z; TO92
JP1, JP2: 2X5; PLD_2X05_PSEUDOSMD
JP3, JP7, JP8, JP9: STAND-OFF
JP4: boot_0; PLD_1X03
JP5: boot_1; PLD_1X03
JP6: M05X2SHD; 2X5-SHROUDED
L1: 1uH; L0603
LED1, LED2: RED; LED-0805
LED3: LED-TRICOLOR-5050
Q1, Q3, Q4: IRLML5203; MICRO3
R1, R2, R3, R7, R8, R10, R15, R16, R17, R18, R19, R20, R21, R22, R23, R24, R45, R48, R54, R55, R59: 10k; 0805
R4, R5: 100; 0805
R6, R64: 0; 1206
R11, R25, R27, R28: 2.7k; 0805
R12, R13: 33; 0805
R14, R29, R56, R57, R58, R61, R75: 1k; 0805
R30: 68; 0805
R31, R60: 0; 0805
R32, R33, R47: 100k; 0805
R36, R51: 47; 0805
R38, R39, R40, R41, R42, R43, R44, R46: 330; 0805
S2: RESET; BUTTON_6X3.5
T3: BC848; SOT23
U2: TMP75DGK; MSOP8
U44: BMP085
VD1, VD2, VD3, VD8: BZV55-C3V3; SOD80C
VD4, VD5: BAR43; SOT23-3
X1: USB-SMD-NS; USB-MINIB-NOSTOP
XP1: 2X10-PSEUDO_SMD; PLD_2X10_PSEUDOSMD
XP2: RECEIVER; PLD_1X03
XP6: sonar; PLD_1X03
XP8: PWM1; PLD_1X03
XP9: PWM2; PLD_1X03
XP10: PWM3; PLD_1X03
XP11: PWM4; PLD_1X03
XP12: PWM5; PLD_1X03
XP13: PWM6; PLD_1X03
XP14: PWM7; PLD_1X03
XP15: PWM8; PLD_1X03
XP16: tacho; PLD_1X03
XP17: power; PLD_1X03
XP18: current_sens; PLD_1X02
ZQ1: 8M; CRYSTAL-SMD-5X3
ZQ2: 32k; CRYSTAL-32KHZ-SMD-3.2X1.5

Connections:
3.3V: C1.1, C2.1, C3.1, C4.1, C5.1, C6.A (+), C20.1, C25.1, C26.2, C27.2, C29.2, C33.A (+), C34.A (+), C35.1, C36.1, C38.1, DA1.3 (OUT), DA6.8 (VDD), DD1.11 (VDD), DD1.19 (VDD), DD1.28 (VDD), DD1.50 (VDD), DD1.75 (VDD), DD1.100 (VDD), DD2.1 (VDDRTC), DD2.13 (VDD), DD2.14 (VDD), DD2.16 (VDD), DD3.3 (VDD), DD3.8 (VLOGIC), DD3.13 (VDD), DD5.1 (VDD_IO), DD5.14 (VDD), JP1.1, JP2.1, JP4.3, JP5.3, JP6.1, LED3.1 (BA), LED3.2 (RA), LED3.3 (GA), Q3.2 (S), Q4.2 (S), R1.2, R7.2, R11.2, R15.1, R16.1, R17.2, R18.2, R19.2, R20.2, R21.2, R25.2, R27.2, R28.2, U2.8 (VDD), U44.3 (VDDA), U44.4 (VDDD), U44.8 (XCLR), VD5.1 (A), XP1.1, XP1.2, XP6.2, XP16.2
5V_ENABLE: DD1.57 (PD10), R61.2
5V_USB: D2.A, X1.VBUS
6V: C31.A (+), C42.1, D3.C, DA1.2 (IN), F1.2, F3.2, L1.1, R55.2, XP2.2
!AD_CS: DA6.4 (!CS), DD1.81 (PD0)
+3.3V_A: C22.1, C24.1, C41.1, C46.1, DA4.5 (OUT), DA5.8 (+V), DA6.7 (!SHDN), DA6.10 (A), DD1.21 (VREF+), DD1.22 (VDD_A), IC2.5 (V+)
+5V_A: C17.1, C50.1, C52.A (+), DA2.1 (VDD), DA3.2 (VCC), IC3.1 (O)
ADIS_INT: DD1.98 (PE1), DD2.15 (DIO2)
ADIS_MISO: DD1.31 (PA6), DD2.22 (DOUT)
ADIS_MOSI: DD1.32 (PA7), DD2.19 (DIN)
ADIS_NRST: DD1.67 (PA8), DD2.18 (!RST), R8.1
ADIS_NSS: DD1.29 (PA4), DD2.20 (!CS)
ADIS_SCK: DD1.30 (PA5), DD2.21 (SCLK)
AD_CLK: DA6.6 (CLK), DD1.26 (PA3)
AD_SDI: DA6.5 (SDI), DD1.82 (PD1)
BMP085_EOC: DD1.3 (PE4), R75.1
BOOT_0: DD1.94 (BOOT_0), R3.2
BOOT_1: DD1.37 (BOOT_1(PB2)), R2.2
CURRENT_SENS: DD1.17 (PC2), IC2.1 (OUT)
EEPROM_PWR_EN: DD1.24 (PA1), Q4.1 (G), R16.2
FROM_GPS: DD1.69 (PA10), JP2.2
FROM_XBEE: DD1.56 (PD9), JP1.2
GND: BAT1.2 (-), C1.2, C2.2, C3.2, C4.2, C5.2, C6.C (-), C7.C (-), C8.1, C9.2, C10.2, C11.1, C12.1, C13.2, C19.1, C20.2, C21.2, C23.1, C25.2, C26.1, C27.1, C28.1, C29.1, C31.C (-), C32.2, C33.C (-), C34.C (-), C35.2, C36.2, C38.2, C40.2, C42.2, C44.1, D3.A, DA1.1 (ADJ), DA6.3 (GND), DD1.10 (GND), DD1.27 (GND), DD1.74 (GND), DD1.99 (GND), DD2.9 (GND), DD2.11 (GND), DD2.12 (GND), DD3.1 (CLKIN), DD3.9 (AD0), DD3.11 (FSYNC), DD3.15 (GND), DD3.17 (GND), DD3.18 (GND), DD4.6 (GND), DD4.9 (SHIELD), DD4.10 (SHIELD), DD4.11 (SHIELD), DD4.12 (SHIELD), DD5.7 (GND), DD5.10 (GND), DD5.11 (GND), IC1.1 (A0), IC1.2 (A1), IC1.3 (A2), IC1.4 (GND), IC1.7 (WP), JP1.10, JP2.10, JP4.1, JP5.1, JP6.2, LED1.C, LED2.C, R6.2, R8.2, R22.1, R23.1, R24.1, R32.2, R64.2, S2.P, U2.4 (GND), U2.5 (A2), U2.6 (A1), U2.7 (A0), U44.1 (GND), VD8.A, X1.GND, XP1.4, XP1.6, XP1.8, XP1.10, XP1.12, XP1.14, XP1.16, XP1.18, XP1.20, XP2.3, XP6.3, XP16.3
GND_A: C14.C (-), C15.2, C16.2, C17.2, C18.2, C22.2, C24.2, C37.1, C39.1, C41.2, C43.2, C46.2, C50.2, C52.C (-), C55.2, DA2.3 (GND), DA3.3 (GND), DA4.2 (GND), DA5.4 (-V), DA6.1 (B), DA6.2 (VSS), DD1.20 (VSS_A), IC2.2 (GND), IC3.2 (GND), R6.1, R47.1, R56.1, R57.1, T3.2 (E), VD1.A, VD2.A, VD3.A
GPS_ENABLE: DD1.97 (PE0), JP2.4
GPS_PPS: DD1.23 (PA0), JP2.7
I2C_FAST_SCL: DD1.47 (PB10), DD3.23 (SCL), DD5.2 (SCL), R28.1
I2C_FAST_SDA: DD1.48 (PB11), DD3.24 (SDA), DD5.3 (SDA), R27.1
I2C_SLOW_SCL: DD1.92 (PB6), IC1.6 (SCL), JP6.5, R25.1, U2.2 (SCL), U44.6 (SCL)
I2C_SLOW_SDA: DD1.93 (PB7), IC1.5 (SDA), JP6.6, R11.1, U2.1 (SDA), U44.7 (SDA)
LED_B: DD1.91 (PB5), R31.2
LED_G: DD1.36 (PB1), R60.2
LED_R: DD1.35 (PB0), R30.2
MAG_INT: DD1.4 (PE5), DD5.9 (DRDY)
MAIN_SUPPLY: R51.1, R54.2, XP18.2
MPU9150_INT: DD1.2 (PE3), R14.2
MPXV_TEMP: C18.1, DD1.16 (PC1), R10.2, VD1.C
unnamed: C9.1, DD1.9 (PC15(OSC32_OUT)), ZQ2.2
unnamed: LED2.A, R4.2
unnamed: JP5.2, R2.1, R4.1
unnamed: LED1.A, R5.2
unnamed: JP4.2, R3.1, R5.1
unnamed: C10.1, DD1.8 (PC14(OSC32_IN)), ZQ2.1
unnamed: C12.2, DD1.13 (OSC_OUT), ZQ1.3
unnamed: LED3.6 (BC), R31.1
unnamed: C11.2, DD1.12 (OSC_IN), ZQ1.1
unnamed: R12.1, X1.D-
unnamed: DA6.9 (W), R45.1
unnamed: LED3.5 (RC), R30.1
unnamed: R13.1, X1.D+
unnamed: D1.C, F3.1
unnamed: C16.1, DA4.4 (BYPASS)
unnamed: DA2.2 (OUT), R10.1
unnamed: R22.2, XP1.19
unnamed: R23.2, XP1.17
unnamed: R24.2, XP1.11
unnamed: C45.1, IC2.4 (IN-), R36.2
unnamed: C28.2, DD3.20 (CPOUT)
unnamed: C19.2, DD3.10 (REGOUT)
unnamed: C7.A (+), C8.2, DD4.4 (VCC), Q3.3 (D)
unnamed: C30.1, DD5.12 (SETP)
unnamed: C21.1, IC1.8 (VCC), Q4.3 (D)
unnamed: DD3.12 (INT), R14.1
unnamed: C30.2, DD5.13 (SETC)
unnamed: C32.1, DD5.6 (C1)
unnamed: BAT1.1 (+), VD4.1 (A)
unnamed: C14.A (+), C15.1, DA4.1 (IN), DA4.3 (EN), L1.2, Q1.2 (S), R59.1
unnamed: LED3.4 (GC), R60.1
unnamed: R29.1, XP2.1
unnamed: C40.1, DD1.6 (V_BAT), VD4.3 (C), VD5.3 (C)
unnamed: DD1.7 (PC13(TAMPER-RTC)), R32.1
unnamed: DA3.4 (OUT), R48.2
unnamed: D2.C, F1.1
unnamed: C45.2, IC2.3 (IN+), R51.2
unnamed: R36.1, XP18.1
unnamed: DA5.2 (-IN), R33.1, R45.2
unnamed: C43.1, DA5.3 (+IN), R47.2, R48.1
unnamed: C37.2, DD1.18 (PC3), R54.1, R56.2, VD2.C
unnamed: C54.1, Q1.1 (G), R58.2
unnamed: C39.2, DD1.33 (PC4), R55.1, R57.2, VD3.C
unnamed: C54.2, C55.1, IC3.3 (I), Q1.3 (D)
unnamed: R61.1, T3.1 (B)
unnamed: R75.2, U44.2 (EOC)
unnamed: R64.1, XP8.3, XP9.3, XP10.3, XP11.3, XP12.3, XP13.3, XP14.3, XP15.3, XP17.3
unnamed: C23.2, DD1.73 (VCAP_2)
unnamed: C44.2, DD1.49 (VCAP_1)
NET$1: R58.1, R59.2, T3.3 (C)
PRESS_DIFF: DA5.1 (OUT), DD1.15 (PC0), R33.2
PWM1: R38.2, XP8.1
PWM2: R39.2, XP9.1
PWM3: R40.2, XP10.1
PWM4: R41.2, XP11.1
PWM5: R42.2, XP12.1
PWM6: R43.2, XP13.1
PWM7: R44.2, XP14.1
PWM8: R46.2, XP15.1
RECEIVER_PPM: DD1.96 (PB9), R29.2, VD8.C
RESET: C13.1, DD1.14 (NRST), R7.1, S2.S, XP1.15
SDC_PWR_EN: DD1.46 (PE15), Q3.1 (G), R15.2
SDIO_CK: DD1.80 (PC12), DD4.5 (SD_CK)
SDIO_CMD: DD1.83 (PD2), DD4.3 (SD_CMD)
SDIO_D0: DD1.65 (PC8), DD4.7 (SD_D0)
SDIO_D1: DD1.66 (PC9), DD4.8 (SD_D1)
SDIO_D2: DD1.78 (PC10), DD4.1 (SD_D2)
SDIO_D3: DD1.79 (PC11), DD4.2 (SD_D3)
SDIO_DETECT: DD1.43 (PE12), DD4.13 (DETECT), R1.1
SONAR_PWM: DD1.25 (PA2), XP6.1
SPI2_MISO_UEXT: DD1.53 (PB14), JP6.7
SPI2_MOSI_UEXT: DD1.54 (PB15), JP6.8
SPI2_NSS_UEXT: DD1.51 (PB12), JP6.10
SPI2_SCK_UEXT: DD1.52 (PB13), JP6.9
TACHOMETER: DD1.95 (PB8), XP16.1
TCK: DD1.76 (JTCK(PA14)), R20.1, XP1.9
TDI: DD1.77 (JTDI(PA15)), R18.1, XP1.5
TDO: DD1.89 (JTDO(PB3)), R21.1, XP1.13
TIM1_CH1: DD1.40 (PE9), R38.1
TIM1_CH2: DD1.42 (PE11), R39.1
TIM1_CH3: DD1.44 (PE13), R40.1
TIM1_CH4: DD1.45 (PE14), R41.1
TIM4_CH1: DD1.59 (PD12), R42.1
TIM4_CH2: DD1.60 (PD13), R43.1
TIM4_CH3: DD1.61 (PD14), R44.1
TIM4_CH4: DD1.62 (PD15), R46.1
TMS: DD1.72 (JTMS(PA13)), R19.1, XP1.7
TO_GPS: DD1.68 (PA9), JP2.3
TO_XBEE: DD1.55 (PD8), JP1.3
TRST: DD1.90 (NJTRST(PB4)), R17.1, XP1.3
USART6_RX_UEXT: DD1.64 (PC7), JP6.4
USART6_TX_UEXT: DD1.63 (PC6), JP6.3
USB_DM: DD1.70 (PA11), R12.2
USB_DP: DD1.71 (PA12), R13.2
V_IN: D1.A, XP8.2, XP9.2, XP10.2, XP11.2, XP12.2, XP13.2, XP14.2, XP15.2, XP17.2
XBEE_CTS: DD1.58 (PD11), JP1.4
XBEE_RESET: DD1.88 (PD7), JP1.5



Board: 2 copper layers, 100.0 x 65.0 mm, 168 parts (109 on the bottom side), 134 nets.

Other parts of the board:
U$2: LOGO_CHIBIOS_SILK

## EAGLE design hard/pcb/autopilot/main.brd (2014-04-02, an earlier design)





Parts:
BAT1: 3V; BATTCOM_20MM_PTH
C1, C2, C3, C4, C5, C8, C13, C15, C19, C20, C21, C22, C24, C25, C27, C28, C29, C32, C33, C36, C37, C38, C42, C43, C50, C54, C55: 0.1uF; 0805
C6, C14, C18, C52: 10uF/6.3v; EIA3216-KIT
C7: 47uF/6.3v; EIA3216-KIT
C9, C10: 10pF; 0805
C11, C12, C16, C17: 20pF; 0805
C23, C44: 2.2uF; 0805
C26, C35, C41: 4.7uF; EIA3216-KIT
C30: 1uF; 0805
C31: 330uF/16v; CPOL-RADIAL-1000UF-25V
C34: 560uF/4v; E3,5-8
C39: 2.2nF/50v; 0805
C40: 0.22uF; 0805
C45: 10uF; 1206
C48: 0.22F/5.5v; CAP-IONISTOR-5MM
C49: 2.2uF; C1206
C51: 10uF/16v; EIA3216-KIT
D2: 10BQ060; SMB
D3: SM6T12V; SMBJ
DA1: LM1117; SOT223
DA2: LMV321M5; SOT23-5
DA3: MPXV5010DP; 482
DA6: LP2980; SOT23-5
DD1: MICROSD_SDIO; MICROSD
DD2: STM32F103VDT6; TQFP100
DD3: HMC5883L; 16LPCC
F1, F3: POLYSWITCH; 1812
IC1: 24AA32ASN; SO-08
IC2: INA194; SOT23-5
IC3: LP2950Z; TO92
JP1, JP2: 2X5; 2X5-PSEUDOSMD
JP3, JP7, JP8, JP9: STAND-OFFTIGHT; STAND-OFF-TIGHT
JP4: boot_0; 1X03
JP5: boot_1; 1X03
JP6: bat; 1X03
L1: 1uH; 1210
LED1, LED2: RED; LED-0805
Q1: IRLML5203; MICRO3
Q2: IRLML5103; MICRO3; PARTNO *
R1, R2, R3, R7, R16, R17, R18, R19, R20, R21, R22, R23, R24, R45, R48, R54, R55, R59: 10k; 0805
R4, R5: 100; 0805
R6, R37, R38, R39, R40, R41, R42, R43, R44, R49, R50, R52: 330; 0805
R8, R25, R53: 2.2; R1206
R9, R31, R60, R65, R70, R73, R74, R76, R77, R78, R79, R80, R81: 0; 0805
R10, R35: 1.5k; 0805
R12, R13: 33; 0805
R15, R27, R28: 2.7k; 0805
R26: 1; 0805
R29, R46, R56, R57, R58, R61, R66, R67, R69, R71, R72, R75: 1k; 0805
R30, R63: 68; 0805
R32, R33, R47: 100k; 0805
R34: 30k; 0805
R36, R51: 47; 0805
R62, R64, R68, R82, R83, R84, R85: 0; R1206
S2: RESET; BUTTON_6X3.5
T3: BC848; SOT23
U1: ITG-3200; QFN-24
U2: TMP75DGK; MSOP8
U3: MAG3110; DFN-10
U4: MMA8451Q; QFN-16_0.5MM
U5: MAX1236EUA+; MSOP8
U44: BMP085
U$7: LED-TRICOLOR; LED-TRICOLOR-SMD
VD8: BZV55-C3V3; SOD80C
X1: USB-SMD-NS; USB-MINIB-NOSTOP
XP1: 2X10-PSEUDO_SMD; 2X10-PSEUDOSMD
XP2: RECEIVER; 1X03
XP3: EXT_5V; 1X02
XP4: an2_5v; 1X02
XP5: EXT3.3V; 1X02
XP6: sonar; 1X03
XP7: SPI_EXT; 1X4-PSEUDOSMD
XP8: PWM1; 1X03
XP9: PWM2; 1X03
XP10: PWM3; 1X03
XP11: PWM4; 1X03
XP12: PWM5; 1X03
XP13: PWM6; 1X03
XP14: PWM7; 1X03
XP15: PWM8; 1X03
XP16: tacho; 1X03
XP17: power; 1X03
XP18: current_sens; 1X02
ZQ1: 8M; HC49U-V
ZQ2: 32k; TC38H

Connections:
3.3V: C1.1, C2.1, C3.1, C4.1, C5.1, C6.A (+), C7.A (+), C8.2, C20.1, C21.1, C27.2, C30.1, C33.2, C34.+, C35.A (+), C37.2, C42.1, C48.1 (+), DA1.2 (OUT), DA1.4 (OUT), DA6.1 (IN), DA6.3 (EN), DD1.4 (VCC), DD2.11 (VDD_5), DD2.28 (VDD_4), DD2.50 (VDD_1), DD2.75 (VDD_2), DD2.100 (VDD_3), DD3.2 (VDD), DD3.4 (S1), DD3.13 (VDDIO), IC1.8 (VCC), JP1.1, JP2.1, JP4.3, JP5.3, JP6.1, L1.1, Q2.2 (S), R1.2, R7.2, R16.2, R17.2, R18.2, R19.2, R20.2, R21.2, R26.2, R27.2, R28.2, U1.13 (VDD), U2.8 (VDD), U3.2 (VDD), U3.8 (VDDIO), U4.1 (VDDIO), U4.14 (VDD), U44.3 (VDDA), U44.4 (VDDD), U44.8 (XCLR), U$7.A, XP1.1, XP1.2, XP5.1, XP16.2
5V: C24.1, C50.1, C52.A (+), DA2.5 (V+), DA3.2 (VCC), IC3.1 (O), R25.2, XP3.1, XP6.2
5V_DOMAIN_ENABLE: DD2.67 (PA8(USART1_CK/TIM1_CH1/MCO)*), R61.2
5V_USB: C18.A (+), C19.1, D2.A, F1.2
6V: C31.1 (+), D2.C, D3.C, DA1.3 (IN), F3.2, Q1.2 (S), R55.2, R59.1, XP2.2
AN3.3V_0: R49.2
AN3.3V_1: R50.2
AN3.3V_2: R52.2
AN5V_0: DA2.4 (OUT), R33.2, U5.1 (AN0)
AN5V_1: U5.2 (AN1), XP4.1
AN5V_2: U5.3 (AN2), XP6.1
AN5V_3/REF: R34.2, U5.4 (AN3/REF)
BMP085_EOC: DD2.5 (PE6(TRACED3/FSMC_A22)*), R75.1
BOOT_0: DD2.94 (BOOT_0), R3.2
BOOT_1: DD2.37 (PB2(BOOT_1)*), R2.2
CURRENT_SENS: DD2.15 (PC0(ADC123_IN10)), IC2.1 (OUT)
FROM_GPS: DD2.69 (PA10(USART1_RX/TIM1_CH3)*), JP2.2
FROM_XBEE: DD2.26 (PA3(USART2_RX/ADC123_IN3/TIM5_CH4/TIM2_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), JP1.2
GND: BAT1.2 (-), C1.2, C2.2, C3.2, C4.2, C5.2, C6.C (-), C7.C (-), C8.1, C9.2, C10.2, C11.1, C12.1, C13.2, C16.1, C17.1, C18.C (-), C19.2, C20.2, C21.2, C23.1, C27.1, C28.1, C29.1, C30.2, C31.2 (-), C32.1, C33.1, C34.-, C35.C (-), C36.1, C37.1, C38.1, C39.1, C41.C (-), C42.2, C44.1, C48.2 (-), C51.C (-), C52.C (-), C55.2, D3.A, DA1.1 (ADJ), DD1.6 (GND), DD1.9 (SHIELD), DD1.10 (SHIELD), DD1.11 (SHIELD), DD1.12 (SHIELD), DD2.10 (VSS_5), DD2.27 (VSS_4), DD2.74 (VSS_2), DD2.99 (VSS_3), DD3.9 (GND), DD3.11 (GND), IC1.1 (A0), IC1.2 (A1), IC1.3 (A2), IC1.4 (GND), IC1.7 (WP), IC3.2 (GND), JP1.10, JP2.10, JP4.1, JP5.1, LED1.C, LED2.C, R9.1, R22.1, R23.1, R24.1, R32.2, R64.2, R65.1, R76.1, S2.P, T3.2 (E), U1.1 (CLKIN), U1.9 (AD0), U1.11 (RESV-G), U1.18 (GND), U2.4 (GND), U2.5 (A2), U2.6 (A1), U2.7 (A0), U3.5 (GND), U3.10 (GND), U4.5 (GND), U4.7 (SA0), U4.10 (GND), U4.12 (GND), U44.1 (GND), VD8.A, X1.GND, XP1.4, XP1.6, XP1.8, XP1.10, XP1.12, XP1.14, XP1.16, XP1.18, XP1.20, XP2.3, XP3.2, XP4.2, XP5.2, XP16.3
GND_A: C14.C (-), C15.2, C22.2, C43.2, DA6.2 (GND), DD2.20 (VREF-), IC2.2 (GND), R9.2, R56.1, R57.1, R77.1
GND_A_5V: C24.2, C25.2, C26.C (-), C49.1, C50.2, DA2.2 (V-), DA3.3 (GND), R35.1, R47.1, R65.2, U5.7 (GND), XP6.3
GPS_ENABLE: DD2.4 (PE5(TRACED2/FSMC_A21)*), JP2.7
GPS_PPS: DD2.97 (PE0(TIM4_ETR/FSMC_NBL0)*), JP2.4
I2C_SCL: DD2.47 (PB10(I2C2_SCL/USART3_TX/TIM2_CH3)*), DD3.1 (SCL), IC1.6 (SCL), R28.1, R73.1, R81.1, U1.23 (SCL), U2.2 (SCL), U3.7 (SCL), U44.6 (SCL)
I2C_SDA: DD2.48 (PB11(I2C2_SDA/USART3_RX/TIM2_CH4)*), DD3.16 (SDA), IC1.5 (SDA), R27.1, R74.1, R80.1, U1.24 (SDA), U2.1 (SDA), U3.6 (SDA), U44.7 (SDA)
ITG-3200_INT: DD2.41 (PE10(FSMC_D7/TIM1_CH2N)*), R69.2
LED_B: DD2.95 (PB8(TIM4_CH3/SDIO_D4/I2C1_SCL/CAN_RX)*), R31.2
LED_G: DD2.93 (PB7(I2C1_SDA/FSMC_NADV/TIM4_CH2/USART1_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), R60.2
LED_R: DD2.92 (PB6(I2C1_SCL/TIM4_CH1/USART1_TX)*), R30.2
MAG_INT: DD2.38 (PE7(FSMC_D4/TIM1_ETR)*), R66.2, R67.1
MAIN_SUPPLY: R51.1, R54.2, XP18.2
MMA8451Q_INT1: DD2.39 (PE8(FSMC_D5/TIM1_CH1N)*), R72.1
MMA8451Q_INT2: DD2.46 (PE15(FSMC_D12/TIM1_BKIN)*), R71.1
unnamed: C9.1, DD2.9 (PC15(OSC32_OUT)), ZQ2.2
unnamed: LED2.A, R4.2
unnamed: JP5.2, R2.1, R4.1
unnamed: LED1.A, R5.2
unnamed: JP4.2, R3.1, R5.1
unnamed: C10.1, DD2.8 (PC14(OSC32_IN)), ZQ2.1
unnamed: DD2.13 (OSC_OUT), R6.2
unnamed: C12.2, R6.1, ZQ1.2
unnamed: C11.2, DD2.12 (OSC_IN), ZQ1.1
unnamed: R12.1, X1.D-
unnamed: BAT1.1 (+), JP6.3
unnamed: L1.2, R8.1
unnamed: R13.1, X1.D+
unnamed: Q2.3 (D), R10.2
unnamed: Q2.1 (G), R15.1, R16.1
unnamed: R22.2, XP1.19
unnamed: R23.2, XP1.17
unnamed: R24.2, XP1.11
unnamed: C45.1, IC2.4 (IN-), R36.2
unnamed: C25.1, C26.A (+), R25.1, U5.8 (VDD)
unnamed: C32.2, U4.2 (BYP)
unnamed: C36.2, U1.10 (REGOUT)
unnamed: C29.2, U3.4 (CAP-R)
unnamed: C38.2, R26.1, R70.1
unnamed: C28.2, U3.1 (CAP-A)
unnamed: C40.1, DD3.8 (SETP)
unnamed: C40.2, DD3.12 (SETC)
unnamed: F1.1, X1.VBUS
unnamed: C39.2, U1.20 (CPOUT)
unnamed: C41.A (+), R68.2
unnamed: R29.1, XP2.1
unnamed: R63.1, U$7.G (GRN)
unnamed: DD2.7 (PC13(TAMPER-RTC)), R32.1
unnamed: C49.2, R46.2, R48.2
unnamed: DD2.32 (PA7(SPI1_MOSI/TIM8_CH1N/ADC12_IN7/TIM3_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), R82.1
unnamed: C45.2, IC2.3 (IN+), R51.2
unnamed: C43.1, R53.1
unnamed: R36.1, XP18.1
unnamed: DD2.62 (PD15(FSMC_D1/TIM4_CH4)*), R39.1
unnamed: DD2.61 (PD14(FSMC_D0/TIM4_CH3)*), R40.1
unnamed: DD2.60 (PD13(FSMC_A18/TIM4_CH2)*), R37.1
unnamed: DD2.59 (PD12(FSMC_A17/USART3_RTS/TIM4_CH1)*), R38.1
unnamed: DA3.4 (OUT), R46.1
unnamed: DD2.34 (PC5(ADC12_IN15)), R52.1
unnamed: DA2.3 (-IN), R33.1, R45.2
unnamed: DA2.1 (+IN), R47.2, R48.1
unnamed: R34.1, R35.2, R45.1
unnamed: DD2.33 (PC4(ADC12_IN14)), R50.1
unnamed: DD2.18 (PC3(ADC123_IN13)), R49.1
unnamed: DD2.31 (PA6(SPI1_MISO/TIM8_BKIN/ADC12_IN6/TIM3_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), R83.1
unnamed: DD2.16 (PC1(ADC123_IN11)), R54.1, R56.2
unnamed: C54.1, Q1.1 (G), R58.2
unnamed: DD2.17 (PC2(ADC123_IN12)), R55.1, R57.2
unnamed: C51.A (+), C54.2, C55.1, IC3.3 (I), Q1.3 (D)
unnamed: R31.1, U$7.B (BLU)
unnamed: R30.1, U$7.R (RED)
unnamed: DD2.30 (PA5(SPI1_SCK/DAC2/ADC12_IN5)), R84.1
unnamed: R61.1, T3.1 (B)
unnamed: DD2.29 (PA4(SPI1_NSS/USART2_CK/DAC1/ADC12_IN4)), R85.1
unnamed: DD2.45 (PE14(FSMC_D11/TIM1_CH4)*), R44.1
unnamed: DD2.44 (PE13(FSMC_D10/TIM1_CH3)*), R43.1
unnamed: DD2.42 (PE11(FSMC_D8/TIM1_CH2)*), R42.1
unnamed: DD2.40 (PE9(FSMC_D6/TIM1_CH1)*), R41.1
unnamed: R67.2, U3.9 (INT1)
unnamed: DD3.15 (DRDY), R66.1
unnamed: DD3.10 (C1), R68.1
unnamed: R69.1, U1.12 (INT)
unnamed: R70.2, U1.8 (VLOGIC)
unnamed: R71.2, U4.9 (INT2)
unnamed: R72.2, U4.11 (INT1)
unnamed: R74.2, U4.6 (SDA)
unnamed: R73.2, U4.4 (SCL)
unnamed: R75.2, U44.2 (EOC)
unnamed: R15.2, R62.2
unnamed: R60.1, R63.2
unnamed: R19.1, R78.2, XP1.7
unnamed: R64.1, XP8.3, XP9.3, XP10.3, XP11.3, XP12.3, XP13.3, XP14.3, XP15.3, XP17.3
unnamed: R80.2, U5.6 (SDA)
unnamed: R81.2, U5.5 (SCL)
unnamed: C23.2, DD2.73 (NC)
unnamed: C44.2, DD2.49 (VSS_1), R76.2
unnamed: DD2.19 (VSS_A), R77.2, R79.2
NET$1: R58.1, R59.2, T3.3 (C)
PWM1: R38.2, XP8.1
PWM2: R37.2, XP9.1
PWM3: R40.2, XP10.1
PWM4: R39.2, XP11.1
PWM5: R41.2, XP12.1
PWM6: R42.2, XP13.1
PWM7: R43.2, XP14.1
PWM8: R44.2, XP15.1
RECEIVER_PPM: DD2.35 (PB0(ADC12_IN8/TIM3_CH3/TIM8_CH2N/TIM1_C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), R29.2, VD8.C
RESET: C13.1, DD2.14 (NRST), R7.1, S2.S, XP1.15
SDIO_CK: DD1.5 (SD_CK), DD2.80 (PC12(UART5_TX/SDIO_CK/USART3_CK)*)
SDIO_CMD: DD1.3 (SD_CMD), DD2.83 (PD2(TIM3_ETR/UART5_RX/SDIO_CMD)*)
SDIO_D0: DD1.7 (SD_D0), DD2.65 (PC8(TIM8_CH3/SDIO_D0/TIM3_CH3)*)
SDIO_D1: DD1.8 (SD_D1), DD2.66 (PC9(TIM8_CH4/SDIO_D1/TIM3_CH4)*)
SDIO_D2: DD1.1 (SD_D2), DD2.78 (PC10(UART4_TX/SDIO_D2/USART3_TX)*)
SDIO_D3: DD1.2 (SD_D3), DD2.79 (PC11(UART4_RX/SDIO_D3/USART3_RX)*)
SDIO_DETECT: DD1.13 (DETECT), DD2.2 (PE3(TRACED0/FSMC_A19)*), R1.1
SPI_EXT_MISO: R83.2, XP7.2
SPI_EXT_MOSI: R82.2, XP7.1
SPI_EXT_NSS: R85.2, XP7.4
SPI_EXT_SCK: R84.2, XP7.3
TACHOMETER: DD2.36 (PB1(ADC12_IN9/TIM3_CH4/TIM8_CH3N/TIM1_C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), XP16.1
TCK: DD2.76 (JTCK/SWCLK(PA14)*), R20.1, XP1.9
TDI: DD2.77 (JTDI(PA15/SPI3_NSS/I2S3_WS/TIM2_CH1_ETR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), R18.1, XP1.5
TDO: DD2.89 (JTDO(PB3/SPI3_SCK/I2S3_CK/TRACEWO/TIM2_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), R21.1, XP1.13
TMP75_ALERT: U2.3 (ALERT)
TMS: DD2.72 (JTMS/SWDIO(PA13)*), R78.1
TO_GPS: DD2.68 (PA9(USART1_TX/TIM1_CH2)*), JP2.3
TO_XBEE: DD2.25 (PA2(USART2_TX/ADC123_IN2/TIM5_CH3/TIM2_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), JP1.3
TRST: DD2.90 (NJTRST(PB4/SPI3_MISO/TIM3_CH1/SPI1_MISO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), R17.1, XP1.3
USB_DISCOVERY: DD2.3 (PE4(TRACED1/FSMC_A20)*), R62.1
USB_DM: C16.2, DD2.70 (PA11(USBDM/CAN_RX/USART1_CTS/TIM1_CH4)*), R12.2
USB_DP: C17.2, DD2.71 (PA12(USBDP/CAN_TX/USART1_RTS/TIM1_ETR)*), R10.1, R13.2
VBAT: DD2.6 (V_BAT), JP6.2
VDD_A: C14.A (+), C15.1, C22.1, DD2.22 (VDD_A), IC2.5 (V+), R8.2, R79.1
VREF_MCU: DA6.5 (OUT), DD2.21 (VREF+), R53.2
V_IN: F3.1, XP8.2, XP9.2, XP10.2, XP11.2, XP12.2, XP13.2, XP14.2, XP15.2, XP17.2
XBEE_CTS: DD2.23 (PA0(WKUP/USART2_CTS/ADC123_IN0/TIM2_CH1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), JP1.4
XBEE_RESET: DD2.1 (PE2(TRACECK/FSMC_A23)*), JP1.5
XBEE_RTS: DD2.24 (PA1(USART2_RTS/ADC123_IN1/TIM5_CH2/TIM2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), JP1.6
XBEE_SLEEP: DD2.98 (PE1(FSMC_NBL1)*), JP1.9



Board: 2 copper layers, 100.0 x 65.0 mm, 195 parts (85 on the bottom side), 153 nets.

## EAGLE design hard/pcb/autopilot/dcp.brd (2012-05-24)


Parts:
C1: 0.1; 0805
JP1: STAND-OFF-M3
R1, R2: 100; 0805
U$1: D21EESX
XP1: PLD_1X03LONGPAD; PLD_1X03_LONGPAD

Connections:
+3V3: C1.1, R1.1, U$1.C (TC), XP1.2
GND: C1.2, R2.2, U$1.K (DC), XP1.3
unnamed: R2.1, U$1.E (TE), XP1.1
unnamed: R1.2, U$1.A (DA)



Board: 2 copper layers, 13.5 x 16.5 mm, 6 parts (3 on the bottom side), 4 nets.

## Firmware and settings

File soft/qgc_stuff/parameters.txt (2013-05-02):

# Onboard parameters for system MAV 020
#
# MAV ID  COMPONENT ID  PARAM NAME  VALUE (FLOAT)
20	0	ACC_sortmtrx	266	5
20	0	ACC_still_flen	256	6
20	0	ACC_still_thr	         0.00999999977648	9
20	0	ACC_xoffset	0	6
20	0	ACC_xpol	-1	6
20	0	ACC_xsens	8192	5
20	0	ACC_yoffset	0	6
20	0	ACC_ypol	-1	6
20	0	ACC_ysens	8192	5
20	0	ACC_zoffset	0	6
20	0	ACC_zpol	-1	6
20	0	ACC_zsens	8192	5
20	0	ADC_MV_gain	8050	5
20	0	ADC_SV_gain	8052	5
20	0	ADC_car_I_b	24841	6
20	0	ADC_car_I_k	580	6
20	0	ADC_plane_I_b	2000	6
20	0	ADC_plane_I_k	50	6
20	0	BAT_cap	1300	5
20	0	BAT_fill	100	5
20	0	DBG_reserved0	0	5
20	0	DBG_reserved1	0	5
20	0	DBG_reserved2	0	5
20	0	FLEN_adc	3	6
20	0	FLEN_climb	5	6
20	0	FLEN_magnetom	512	6
20	0	FLEN_pres_dyn	3	6
20	0	FLEN_pres_stat	5	6
20	0	FLEN_reserved2	6	6
20	0	FLEN_reserved3	6	6
20	0	FLEN_reserved4	6	6
20	0	GYRO_sendangle	1	5
20	0	GYRO_sortmtrx	140	5
20	0	GYRO_stillthr	            0.10000000149	9
20	0	GYRO_x_offset	           -21.2685375214	9
20	0	GYRO_xpol	1	6
20	0	GYRO_xsens	                   14.375	9
20	0	GYRO_y_offset	            6.66338682175	9
20	0	GYRO_ypol	-1	6
20	0	GYRO_ysens	                   14.375	9
20	0	GYRO_z_offset	             42.552532196	9
20	0	GYRO_zerocnt	512	6
20	0	GYRO_zeroflen	512	6
20	0	GYRO_zpol	-1	6
20	0	GYRO_zsens	                   14.375	9
20	0	HEAD_dGain	                        0	9
20	0	HEAD_iGain	                        0	9
20	0	HEAD_iMax	                        2	9
20	0	HEAD_iMin	                       -2	9
20	0	HEAD_pGain	                        1	9
20	0	IMU_accweight	         0.00499999988824	9
20	0	IMU_ahrsmode	0	5
20	0	IMU_beta	         0.00999999977648	9
20	0	IMU_gpsweight	         0.00499999988824	9
20	0	IMU_magweight	         0.00499999988824	9
20	0	IMU_reset	0	5
20	0	IMU_zeta	                        0	9
20	0	MAG_dcm_00	                        1	9
20	0	MAG_dcm_01	                        0	9
20	0	MAG_dcm_02	                        0	9
20	0	MAG_dcm_10	                        0	9
20	0	MAG_dcm_11	                        1	9
20	0	MAG_dcm_12	                        0	9
20	0	MAG_dcm_20	                        0	9
20	0	MAG_dcm_21	                        0	9
20	0	MAG_dcm_22	                        1	9
20	0	MAG_declinate	0	6
20	0	MAG_ellip_00	          -0.649999976158	9
20	0	MAG_ellip_10	         -0.0480000004172	9
20	0	MAG_ellip_11	          -0.660000026226	9
20	0	MAG_ellip_20	          0.0403999984264	9
20	0	MAG_ellip_21	          0.0185000002384	9
20	0	MAG_ellip_22	          -0.717999994755	9
20	0	MAG_sortmtrx	273	5
20	0	MAG_still_flen	256	6
20	0	MAG_still_thr	            1.79999995232	9
20	0	MAG_vectorlen	                       50	9
20	0	MAG_xoffset	                        0	9
20	0	MAG_xpol	-1	6
20	0	MAG_xsens	                       11	9
20	0	MAG_yoffset	                        0	9
20	0	MAG_ypol	1	6
20	0	MAG_ysens	            9.80000019073	9
20	0	MAG_zerocnt	1024	6
20	0	MAG_zeroflen	1024	6
20	0	MAG_zoffset	                        0	9
20	0	MAG_zpol	1	6
20	0	MAG_zsens	                       11	9
20	0	PMU_reserved0	50	6
20	0	PMU_reserved1	2000	6
20	0	SERVO_0_max	2000	5
20	0	SERVO_0_min	1000	5
20	0	SERVO_0_neutr	1500	5
20	0	SERVO_1_max	2000	5
20	0	SERVO_1_min	1000	5
20	0	SERVO_1_neutr	1500	5
20	0	SERVO_2_max	2000	5
20	0	SERVO_2_min	1000	5
20	0	SERVO_2_neutr	1500	5
20	0	SERVO_3_max	2000	5
20	0	SERVO_3_min	1000	5
20	0	SERVO_3_neutr	1500	5
20	0	SERVO_4_max	2000	5
20	0	SERVO_4_min	1000	5
20	0	SERVO_4_neutr	1500	5
20	0	SERVO_5_max	2000	5
20	0	SERVO_5_min	1000	5
20	0	SERVO_5_neutr	1500	5
20	0	SERVO_6_max	1000	5
20	0	SERVO_6_min	2000	5
20	0	SERVO_6_neutr	1500	5
20	0	SERVO_7_max	2000	5
20	0	SERVO_7_min	1000	5
20	0	SERVO_7_neutr	1500	5
20	0	SERVO_car_dz	16	5
20	0	SERVO_car_max	2000	5
20	0	SH_overxbee	0	5
20	0	SPD_dGain	                        0	9
20	0	SPD_iGain	          0.0120000001043	9
20	0	SPD_iMax	                      100	9
20	0	SPD_iMin	                     -100	9
20	0	SPD_pGain	                    0.125	9
20	0	SPD_pulse2m	          0.0555555485189	9
20	0	SPD_speed_max	                       60	9
20	0	SPD_speed_min	           0.800000011921	9
20	0	SYS_ID	20	5
20	0	SYS_mavtype	10	5
20	0	TIME_zone	3	6
20	0	T_attitude	200	5
20	0	T_gps_int	0	5
20	0	T_nav_output	0	5
20	0	T_position_ned	0	5
20	0	T_raw_imu	200	5
20	0	T_raw_press	0	5
20	0	T_scal_imu	200	5
20	0	T_scal_press	0	5
20	0	T_sys_status	100	5
20	0	T_vfr_hud	0	5
20	0	XTRACK_dGain	                        0	9
20	0	XTRACK_iGain	                        0	9
20	0	XTRACK_iMax	                        0	9
20	0	XTRACK_iMin	                        0	9
20	0	XTRACK_pGain	                        0	9
20	0	param_end_mark	0	5

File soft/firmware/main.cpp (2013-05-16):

/*                      WARNINGS!
 *
 * cmpilation without -fomit-frame-pointer cause stack overflows.
 */

/*
Hi,
I also had the same problem interfacing to an I2C device. However I solved the issue by changing the relevant outputs to open drain by editing the board.h file. Therefore palSetPadMode(i2c_gpio->sda_gpio_port, i2c_gpio->sda_gpio, PAL_MODE_ALTERNATE(4)); is still correct if your board.h file configurse these pins as opendrain.
However, I set my pins to alternate mode in board.h, which is processed before the call to i2cStart(). This works but is there any negative effect from connecting to a alternative peripheral before activating it?
Pilt

Hi,
Setting the alternate function before activating the peripheral can create problems.
For example, the USART TX line is set to zero until the clock is activated and this creates a spurious start bit if the alternate is set in board.h (before the driver is activated).
The safest way to initialize peripherals like USART and I2C is the following (I2C case).
1) In board.h set the pins as *normal* outputs with open drain and an acceptable idle logic state (idle is one for I2C if I remember well).
2) Start the peripheral clock using i2cStart(), the pins are still normal outputs and keep their idle state.
3) Now switch to alternate(4) with open drain and the pins state will go from idle to idle, no transients.
Giovanni
*/

// TODO: save DCM in bkp for faster startup after panic recovery
// TODO: params in bkp
// TODO: gyro update period in bkp
// TODO: save mission data in bkp for recovery if panic occured during mission

// TODO: log compressed format
// TODO: cli for format, ls, rm

// TODO: rewrite stab code in general case using aviation formulae.
// TODO: probably migrate from float32 to double in coordinate calculations.

// TODO: correct STOP handling in waypoint algorithm (incorrect realization in QGC)

// TODO: speed autosetting
// TODO: combine barometer and accelerometer in one filter.
// TODO: Power brown out handler (using ADC comparator on power supply pin?) for sync/umout SDC.
// TODO: One more point in dynamic pressure thermal compensation algorithm (at +60 celsius)
// TODO: Rewrite XBee code for use DMA.
// TODO: WDT?

#include <time.h>

#include "main.h"
#include "global_flags.h"
#include "fault_handlers.h"
#include "message.hpp"
#include "gps.hpp"
#include "sanity.hpp"
#include "i2c_local.hpp"
#include "eeprom_file_tree.hpp"
#include "param.hpp"
#include "timekeeping.hpp"
#include "sensors.hpp"
#include "pwr_mgmt.hpp"
#include "microsd.hpp"
#include "tlm_sender.hpp"
#include "linkmgr.hpp"
#include "controller.hpp"
#include "mission_planner.hpp"
#include "benchmark.hpp"
#include "blinker.hpp"
#include "waypoint_db.hpp"
#include "mission_updater.hpp"

#include "imu.hpp"
#include "acs_rover.hpp"
#include "sins.hpp"
#include "drivetrain.hpp"

/*
 ******************************************************************************
 * EXTERNS
 ******************************************************************************
 */
/* RTC-GPS sync */
chibios_rt::BinarySemaphore rtc_sem(true);

/* Servo-PID sync */
chibios_rt::BinarySemaphore servo_updated_sem(true);

/* store here time from GPS */
struct tm gps_timp;

/* some global flags */
GlobalFlags_t GlobalFlags = {0,0,0,0,0,0,0,0,
                             0,0,0,0,0,0,0,0,
                             0,0,0,0,0,0,0,0,
                             0,0,0,0,0,0,0,0};

/* heap for some threads */
MemoryHeap ThdHeap;
static uint8_t link_thd_buf[THREAD_HEAP_SIZE + sizeof(stkalign_t)];

/**/
uint8_t currWpFrame = MAV_FRAME_GLOBAL;

/* new waypoint number for overwrite current */
uint16_t WpSeqNew = 0;

/* save here flags before clear them from MCU register */
uint32_t LastResetFlags;

/* semaphores to sync with external interrupts from sensors */
chibios_rt::BinarySemaphore mma8451_sem(true);
chibios_rt::BinarySemaphore bmp085_sem(true);
chibios_rt::BinarySemaphore itg3200_sem(true);
chibios_rt::BinarySemaphore lsm303_sem(true);
chibios_rt::BinarySemaphore imu_sem(true);

chibios_rt::MailboxBuffer<2> red_blink_mb;
chibios_rt::MailboxBuffer<2> blue_blink_mb;

/* waypoint DB interface */
WpDB wpdb;

/* State vector of system. Caclculated mostly in IMU, used mostly in ACS */
StateVector state_vector;

/* Structure to pass impacts from IMU to ACS */
Impact impact;

/* inertial measurement unit */
IMU imu;

/* automated control system */
ACSRover acs_rover(&state_vector, &impact);

/* automated control system */
SINS sins(&state_vector);

/**/
Drivetrain drivetrain(&impact);

/**/
MissionPlanner mission_planner;

/*
 ******************************************************************************
 * GLOBAL VARIABLES
 ******************************************************************************
 */


/*
 *******************************************************************************
 *******************************************************************************
 * LOCAL FUNCTIONS
 *******************************************************************************
 *******************************************************************************
 */
int main(void) {
  halInit();
  System::init();
  chThdSleepMilliseconds(1);

  /* enable softreset on panic */
  setGlobalFlag(GlobalFlags.allow_softreset);
  if (was_softreset() || was_padreset()){
    chThdSleepMilliseconds(1);
  }
  else
    chThdSleepMilliseconds(100);

  /* give power to all needys */
  pwr5v_power_on();
  gps_power_on();
  xbee_reset_clear();
  xbee_sleep_clear();

  chHeapInit(&ThdHeap, (uint8_t *)MEM_ALIGN_NEXT(link_thd_buf), THREAD_HEAP_SIZE);

  MsgInit();
  BlinkerInit();
  SanityControlInit();
  I2CInitLocal();
  EepromFileTreeInit();
  ParametersInit();   /* read parameters from EEPROM via I2C*/
  MavInit();          /* mavlink constants initialization must be called after parameters init */
  MissionUpdaterInit();
  ControllerInit();
  LinkMgrInit();      /* launch after controller to reduce memory fragmentation on thread creation */
  TimekeepingInit();
  SensorsInit();      /* Note! Sensors depends on I2C */
  PwrMgmtInit();
  TlmSenderInit();
  StorageInit();

  /**/
  LastResetFlags = RCC->CSR;
  clear_reset_flags();

  /* main cycle */
  imu.start();
  acs_rover.start();
  drivetrain.start();
  sins.start();

  while (TRUE){
    if (IMU_UPDATE_RESULT_OK == imu.update(&state_vector)){
      sins.update();
      if (ACS_STATUS_ERROR == acs_rover.update())
        chDbgPanic("");
      drivetrain.update();
    }
  }
  return 0;
}

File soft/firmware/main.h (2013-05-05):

#ifndef MAIN_H_
#define MAIN_H_

/* chibios includes */
#include "ch.hpp"
#include "hal.h"

using namespace chibios_rt;

/* Heap size for dynamic thread creation */
#define THREAD_HEAP_SIZE    (1024 * 4)

/*******************************************************************
 * humanreadable names of serial drivers */
#define XBEESD    SD2
#define GPSSD     SD1

/******************************************************************
 * Disarm halting on panic and changing it to soft reset after this amount of time */
#define HALT_DISARM_TMO_SEC     30

/******************************************************************
 * use hardcoded value instead of measured */
#define GYRO_UPDATE_PERIOD_HARDCODED     TRUE

/******************************************************************
 * приоритеты для потоков */
#define I2C_THREADS_PRIO          (NORMALPRIO - 5)
#define TIMEKEEPER_THREAD_PRIO    (I2C_THREADS_PRIO - 1)
#define LINK_THREADS_PRIO         (NORMALPRIO - 5)
#define CONTROLLER_THREADS_PRIO   (NORMALPRIO)
#define CMD_THREADS_PRIO          (LINK_THREADS_PRIO - 2)
#define GPS_THREAD_PRIO           (NORMALPRIO - 2)

/******************************************************************
* статусы возвращаемые разными подсистемами */
#define PARAM_SUCCESS     CH_SUCCESS
#define PARAM_FAILED      CH_FAILED
#define MISSION_SUCCESS   CH_SUCCESS
#define MISSION_FAILED    CH_FAILED
#define LINK_SUCCESS      CH_SUCCESS
#define LINK_FAILED       CH_FAILED
#define TLM_SUCCESS       CH_SUCCESS
#define TLM_FAILED        CH_FAILED
#define WP_SUCCESS        CH_SUCCESS
#define WP_FAILED         CH_FAILED

/******************************************************************
* константы для мавлинка */
#define GROUND_STATION_ID   255


/* метка времени для пакетов */
#if (CH_FREQUENCY) >= 1000
#define TIME_BOOT_MS ((chTimeNow()) / ((CH_FREQUENCY) / 1000))
#endif

/******************************************************************
* дефайны для модема */
#define BAUDRATE_XBEE 115200
#define xbee_reset_assert() {palClearPad(GPIOE, GPIOE_XBEE_RESET);}
#define xbee_reset_clear()  {palClearPad(GPIOE, GPIOE_XBEE_RESET);}
#define xbee_sleep_assert() {palSetPad(GPIOE, GPIOE_XBEE_SLEEP);}
#define xbee_sleep_clear()  {palSetPad(GPIOE, GPIOE_XBEE_RESET);}

/******************************************************************
* DCM helpers */
/*
 *       | Rxx Rxy Rxz |
 * DCM = | Ryx Ryy Ryz |
 *       | Rzx Rzy Rzz |
 */
#define DCM dcmEst /* our pseudonim */

#define Rxx (DCM[0][0])
#define Rxy (DCM[1][0])
#define Rxz (DCM[2][0])

#define Ryx (DCM[0][1])
#define Ryy (DCM[1][1])
#define Ryz (DCM[2][1])

#define Rzx (DCM[0][2])
#define Rzy (DCM[1][2])
#define Rzz (DCM[2][2])


/******************************************************************
* powering of 5 volt domain */
#define pwr5v_power_on()  {palSetPad(GPIOA, GPIOA_5V_DOMAIN_EN);}
#define pwr5v_power_off() {palClearPad(GPIOA, GPIOA_5V_DOMAIN_EN);}

/* stop watchdog timer in debugging mode */
/*unlock PR register*/
/*set 1.6384s timeout*/
/*start watchdog*/
#define WATCHDOG_INIT {\
    DBGMCU->CR |= DBGMCU_CR_DBG_IWDG_STOP;\
    IWDG->KR = 0x5555;\
    IWDG->PR = 16;\
    IWDG->KR = 0xCCCC;}

#define WATCHDOG_RELOAD {IWDG->KR = 0xAAAA;}


#endif /* MAIN_H_ */

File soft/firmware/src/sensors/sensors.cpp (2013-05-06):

#include "main.h"
#include "sensors.hpp"
#include "global_flags.h"
#include "adc_local.hpp"
#include "exti_local.hpp"
#include "gps.hpp"
#include "imu.hpp"
#include "speedometer.hpp"

#include "tmp75.hpp"
#include "bmp085.hpp"
#include "max1236.hpp"

/*
 ******************************************************************************
 * DEFINES
 ******************************************************************************
 */
#define ACCEL_SEM_TMO       MS2ST(100)
#define BMP085_SEM_TMO      MS2ST(100)

/*
 ******************************************************************************
 * EXTERNS
 ******************************************************************************
 */
RawData raw_data;
CompensatedData comp_data;
extern GlobalFlags_t GlobalFlags;
extern chibios_rt::BinarySemaphore bmp085_sem;

/*
 ******************************************************************************
 * GLOBAL VARIABLES
 ******************************************************************************
 */
static TMP75    tmp75(&I2CD2,   tmp75addr);
static BMP085   bmp085(&I2CD2,  bmp085addr);
static MAX1236  max1236(&I2CD2, max1236addr);

/*
 ******************************************************************************
 * PROTOTYPES
 ******************************************************************************
 */

/*
 *******************************************************************************
 *******************************************************************************
 * LOCAL FUNCTIONS
 *******************************************************************************
 *******************************************************************************
 */
/**
 *
 */
static WORKING_AREA(PollTmp75ThreadWA, 256);
static msg_t PollTmp75Thread(void *arg){
  chRegSetThreadName("Tmp75");
  (void)arg;

  tmp75.start();
  while (!chThdShouldTerminate()) {
    chThdSleepMilliseconds(2000);
    tmp75.update();
  }
  tmp75.stop();
  chThdExit(0);
  return 0;
}

/**
 * Polling thread
 */
static WORKING_AREA(PollBaroThreadWA, 256);
static msg_t PollBaroThread(void *arg){
  (void)arg;

  chRegSetThreadName("Bmp085");
  int32_t retry = 20;
  msg_t sem_status = RDY_OK;

  bmp085.start();
  while (!chThdShouldTerminate()) {
    sem_status = bmp085_sem.waitTimeout(BMP085_SEM_TMO);
    if (sem_status != RDY_OK){
      retry--;
      chDbgAssert(retry > 0, "PollAccelThread(), #1",
          "probably no interrupts from pressure sensor");
    }
    bmp085.update();
  }

  bmp085.stop();
  chThdExit(0);
  return 0;
}

/**
 *
 */
static WORKING_AREA(PollMax1236ThreadWA, 256);
static msg_t PollMax1236Thread(void *arg) {
  chRegSetThreadName("Max1236");
  (void)arg;

  max1236.start();
  while (!chThdShouldTerminate()) {
    chThdSleepMilliseconds(20);
    max1236.update();
  }

  max1236.stop();
  chThdExit(0);
  return 0;
}

/*
 *******************************************************************************
 * EXPORTED FUNCTIONS
 *******************************************************************************
 */
void SensorsInit(void){
  chDbgCheck(GlobalFlags.i2c_ready == 1, "bus not ready");

  /* EXTI start. REMEMBER! I2C slaves and RTC need EXTI.*/
  ExtiInitLocal();
  ADCInitLocal();

  /* start different I2C sensors */
  chThdCreateStatic(PollTmp75ThreadWA,
          sizeof(PollTmp75ThreadWA),
          I2C_THREADS_PRIO,
          PollTmp75Thread,
          NULL);

  chThdCreateStatic(PollMax1236ThreadWA,
          sizeof(PollMax1236ThreadWA),
          I2C_THREADS_PRIO,
          PollMax1236Thread,
          NULL);

  chThdCreateStatic(PollBaroThreadWA,
          sizeof(PollBaroThreadWA),
          I2C_THREADS_PRIO,
          PollBaroThread,
          NULL);

  SpeedometerInit();
  GPSInit();
}

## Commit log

2012-01-20 added hardware files
    [bec.sch, bmp085.brd, bmp085.sch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]
2012-01-20 added software files
    [template.cfg]
2012-01-24 splitting of gyro and adc code finished
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2012-01-25 i2c rework
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2012-01-27 minor i2c fixes
2012-01-28 deleted blinker thread rudiment
2012-01-29 tuning priorities to avoid i2c data losts
    [halconf.h, main.h, mcuconf.h]
2012-01-30 added raw pressure message
2012-01-30 deleted sending code from BMP085 driver
2012-01-31 small fixes in timestamp code
    [main.c]
2012-02-01 small fix in adc code
2012-02-01 added magnetometes coefficients to param struct
2012-02-01 raw imu data fills in personal threads
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2012-02-04 Eeprom code reworked and checked with test suit. Works fine.
    [main.c, param.c]
2012-02-06 fixed fatal typo in param.c
    [param.c]
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2012-02-12 switching between shell and mavlink finished
2012-03-03 added stubs for arm compiler
2012-03-05 switching to CR+LF line endings
2012-03-18 pressure sensor sensitivity fixed
2012-03-18 approximation polinome for pressure fixed
    [param.c]
2012-03-19 added new 3-order approximation sheet for pressure sensor
2012-03-21 gyro code fixes
2012-03-25 gyro code improvemetns. Works zeroing and angle keeping
2012-04-14 added battery filling counter
2012-04-14 fixes in current calculation code
2012-04-28 fixed poligons for LUT
    [main.brd]
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2012-04-30 fixes in parameter checking code
    [main.c, param.c]
2012-04-30 fixed logick in I2C polling threads
2012-05-02 tachometer connected to timer input
    [main.brd, main.sch]
2012-05-05 added magnetometer support to DCM
2012-05-09 semaphores for sensors incapsulated
2012-05-09 some data structures moved from message.h to sensors.h
2012-05-09 call of ADC init moved to SensorsInit()
2012-05-09 IMU init code calls fro SensorsInit()
2012-05-09 GPS init code calls fro SensorsInit()
2012-05-09 added threads for sending different data
2012-05-23 added speedometer PCB"
    [dcp.brd, dcp.sch]
2012-05-25 magnetic measurements successfully integrated
2012-05-28 fixed gain in magnetometer code
    [param.c]
2012-05-31 fixed some signed-unsigned comparisons
    [param.c]
2012-06-03 added code for filter generator and visulizer
2012-06-08 added log writing frequency regulator
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2012-06-08 gps code moved to sensors folder
2012-06-09 RAM optimisation by reducing threads working areas
2012-06-09 RAM optimisation by reducing threads working areas 2 step
2012-07-11 bmp085 filtered via FIR but not tested
2012-07-12 removed FIR code from bmp085 driver
2012-07-12 added filtering to ADC
2012-07-12 added filter to air speed meter. Works not as good as desired
2012-07-24 cosmetical improvements of dynamic pressure measurement
2012-07-25 new code supported variable types finalized and tested
    [parameters.txt]
2012-07-27 improved red LED signaling
2012-07-27 fixed alpha-beta filter code
    [main.c]
2012-07-27 removed hardcoded filter length
2012-07-27 remove hardcoding from ADC code
2012-07-28 baterry capacity meter fixed
    [main.c]
2012-07-28 battery pecentage code fix
    [main.c]
2012-07-28 battery pecentage code fix 2
2012-07-28 battery pecentage code fix 3
2012-07-28 table thermo compensation for pressure sensor done
2012-08-02 convert all line endign to windows style
    [parameters.txt]
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2012-08-06 code structure reorganised
    [parameters.txt]
2012-08-06 power managment moved to separate files
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2012-08-10 exti sources moved to sensors dir
2012-08-14 servo code moved to new location
2012-08-15 CLI realized for servo controlling in ground rover mode
2012-08-15 controller thread now creates from heap
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2012-08-24 fixed 5 point median filter and added 3 point relaization
2012-08-24 switched exti tachometer to 3 point median filter
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2012-08-26 added controller CLI template copypasted from servo CLI
2012-09-04 parameter variable switched to const type to avoid accidental modification
    [main.c]
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2012-09-06 fixed for new chibios
    [mcuconf.h]
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2012-09-19 fixed overflows in heading
    [param.c]
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2012-09-24 magnetic declination must be substructed (not added) to yaw
2012-09-24 added alpha-beta filter for heading. Not tested at all
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2012-10-09 fixed potential bug with pointer to dynamically created thread
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2012-10-12 fix for previouse commit
    [main.c, uav.h]
2012-10-17 returning pointers to dynamically created threads moved to static variables
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2012-10-24 all shell commands now receive pointer to serial driver as parameter
2012-10-27 add some checks to prevent initialization before parameters acquired from eeprom
    [main.c, param.c, uav.h]
2012-10-28 i2c sensors' init code split to full and short parts
    [main.c]
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2012-10-29 fixed wrong axis placement
    [main.c]
2012-10-30 soft reset handles correctly for now
    [main.c]
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2012-11-05 fixed integer power functions
2013-01-23 data sending via events works. WPS need to be reworked
    [main.c, param.c]
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2013-03-17 improved gyro zeroing procedure
    [parameters.txt]
2013-03-20 gyro calibration state grouped to single context structure
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2013-04-18 fixed all implicit conversion from float to double
    [controller.c]
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2013-04-21 added filter in magnetometer code
    [parameters.txt]
2013-04-23 added cosher parameters backup
    [parameters.txt]
2013-04-23 Added immobility detector based on accelerometer
    Need to add tunable threshold
2013-04-25 added immobility detector based on accelerometer
    [parameters.txt]
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2013-04-29 added switcher between intergrated gyroscope angles and angular rates
2013-04-30 Lots of improvements in AHRS code.
    1) All raw data from sensors now converts to NUE coordinates.
    2) When passed to DCM orientation algorithm they converts
    to NWU
    3) Cleaups in Madgwick algorithm
2013-04-30 added switche between mdgwick ahrs and dcm ahrs
2013-05-01 code cleanups
    [parameters.txt]
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2013-05-02 waypoint loading code works
    [parameters.txt]
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2013-05-12 crosstrack error code tested in software
    [acs.cpp, gen_param_struct.py]
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2013-05-16 added reset of XTD pid on WP reaching
    [acs.cpp]
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2014-03-31 Board. NOP
    [main_v2.sch]
2014-04-01 Main board v2 looks finalized
    [main_v2.sch]
2014-04-01 Added board v2
    [main_v2.brd, main_v2.sch]
2014-04-01 Changed in PCB
    [main_v2.brd, main_v2.sch]
2014-04-03 Board v2
    [main_v2.brd, main_v2.sch]
2014-04-05 board v2 nop
    [main_v2.brd, main_v2.sch]
2014-04-06 board v2. nop
    [main_v2.brd, main_v2.sch]
2014-04-07 board v2. Minor fixes
    [main_v2.brd, main_v2.sch]
2014-04-07 board v2. Added capacitor for ADC
    [main_v2.brd, main_v2.sch]
2014-05-19 Added 5mm 3color led
    [main_v2.brd, main_v2.sch]
2014-05-19 updated todo
    [main_v2.brd]
2014-05-25 cosmetical improvements
    [main_v2.brd, main_v2.sch]
2014-06-02 Main board. Final cut
    [main_v2.brd, main_v2.sch]
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2014-11-10 Added kalman hardware
    [main_v2.brd, main_v2.sch]
2014-11-11 PCB routed
    [main_v2.brd, main_v2.sch]
2014-11-11 Board minor fixes
    [main_v2.brd, main_v2.sch]
2015-01-26 updated kalman tester
    [kalman.brd, kalman.sch]
2015-02-08 Updated schematic
    [main_v2.brd, main_v2.sch]
2015-02-18 Fixed pinout for external connector
    [kalman.sch]
2015-06-02 Added board for GPS receiver
    [gps-neo-n8.brd, gps-neo-n8.sch]
2015-06-03 update gps NEO board
    [gps-neo-n8.brd, gps-neo-n8.sch]
2015-06-26 Added motor driver board
    [L293.brd, L293.sch]
2015-07-04 L239 rework
    [L293.brd, L293.sch]

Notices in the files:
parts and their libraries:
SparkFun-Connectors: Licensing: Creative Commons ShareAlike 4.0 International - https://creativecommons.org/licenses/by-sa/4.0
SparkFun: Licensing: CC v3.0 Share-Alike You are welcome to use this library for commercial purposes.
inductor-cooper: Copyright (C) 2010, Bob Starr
